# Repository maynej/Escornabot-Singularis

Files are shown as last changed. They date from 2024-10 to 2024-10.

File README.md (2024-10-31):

# Escornabot-Singularis

Es tracta d'una copia de l'estructura original i una adaptació per utilitzar una bateria recarregable. 

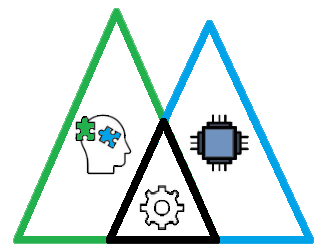
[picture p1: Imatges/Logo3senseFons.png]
Realitzada per [Jordi Mayné](https://github.com/maynej) des de Mechatronic Study 

Escornabot es un projecte obert (https://escornabot.com) 

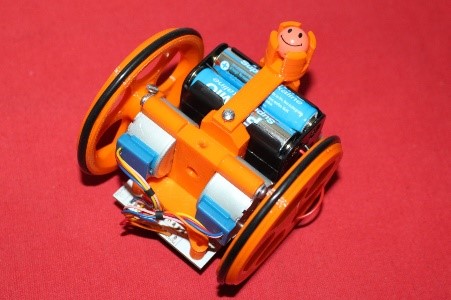
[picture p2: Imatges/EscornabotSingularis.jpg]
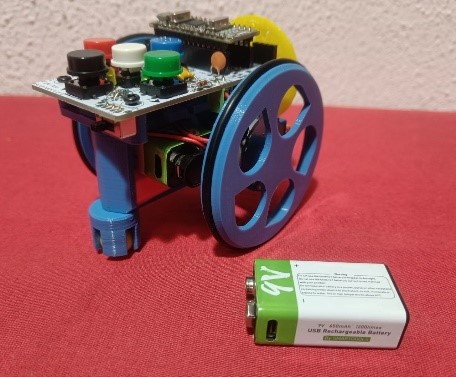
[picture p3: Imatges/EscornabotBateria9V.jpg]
 

El [Manual es pot trobar en PDF](https://github.com/maynej/Escornabot-Singularis/tree/master/DOC/). Inclós en llengua castellana, francés i anglès.

El [Funcionament del firmware es pot trobar en PDF](https://github.com/maynej/Escornabot-Singularis/tree/master/Funcionament/).

També es pot programar amb Arduinoblocks 
de mans de [Manuel Hidalgo](https://github.com/maynej/Escornabot-Singularis/tree/master/Arduinoblocks/). 

STL per imprimir [aquí](https://github.com/maynej/Escornabot-Singularis/tree/master/STL).

Material recopilat de [Xoan Sampaiño](https://github.com/xoan), [Rafa Couto](https://github.com/rafacouto), [XDeSIG](https://github.com/xdesig), [Jorge Lobo Martínez](https://github.com/lobotic) i [mgesteiro](https://github.com/mgesteiro)   
  
# Escornabot Singularis
  
Descripció         | Imatge          | STL         
------------- | ------------- | ------------- 
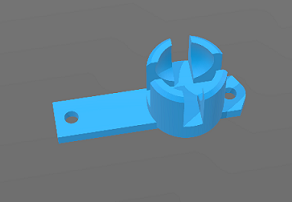
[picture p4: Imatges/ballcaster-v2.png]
Suport bola| | [Suport bola](STL/ballcaster-v2.stl)  
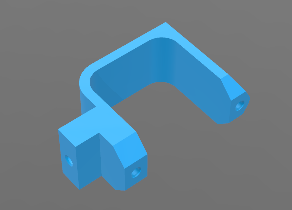
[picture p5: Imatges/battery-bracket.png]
Suport piles| | [Suport piles](STL/battery-bracket.stl)  
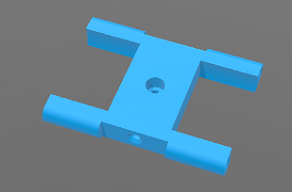
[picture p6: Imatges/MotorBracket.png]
Suport motors| | [Suport Motors](STL/MotorBracket.stl)  
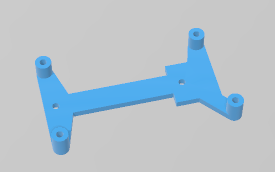
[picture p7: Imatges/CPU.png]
Suport CPU| | [Suport CPU](STL/cpu-2_10-bracket.stl)  
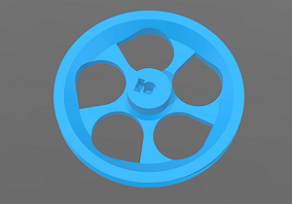
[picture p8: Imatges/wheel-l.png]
Roda esquerra| | [Roda esquerra](STL/wheel-l.stl)  
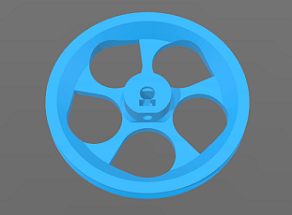
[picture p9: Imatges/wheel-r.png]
Roda dreta| | [Roda dreta](STL/wheel-r.stl)  
  
### Opcións Bateria (explicat en el Manual)
  
Descripció         | Imatge          | STL          
------------- | ------------- | ------------- 
Afegit per Bateria| | [Afegit bateria](STL/TopeBateria9V.stl)  
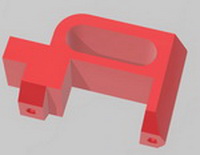
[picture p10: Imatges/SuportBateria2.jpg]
Suport Bateria| | [Suport bateria](STL/BatteryBallcaster2.stl)  

## QR



## Llicència

Creative Commons Attribution-NoComercial-ShareAlike 4.0 International (CC BY-NC-SA 4.0)

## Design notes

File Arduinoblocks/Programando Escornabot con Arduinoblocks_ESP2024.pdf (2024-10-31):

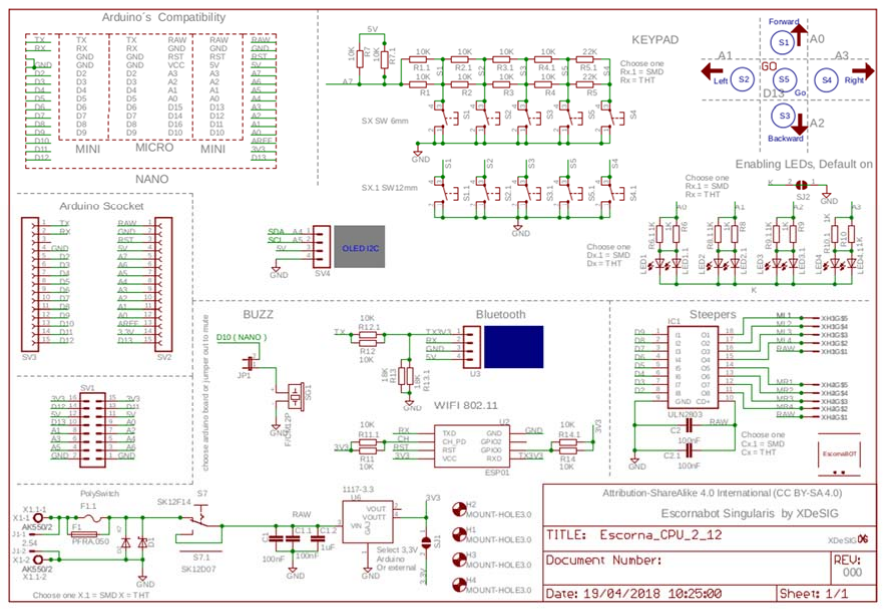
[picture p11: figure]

JORDI MAYNE 2024 | 1

Programando Escornabot con Arduinoblocks.

Manuel Hidalgo - LeoBot

Divulgador de Robóca Educava y OpenSource

hps://leobotmanuel.github.io/Programando-Escornabot/about/

El robot Escornabot es un recurso educavo apropiado para desarrollar el Pensamiento Computacional en edades tempranas por su facilidad de programar sus movimientos y su ulización transversal en casi todos los contenidos educavos de aprendizaje.

En este proyecto se va a ulizar Escornabot para aprender a programar el robot con un lenguaje de programación visual como es Arduinoblocks.

Previamente se ene que conocer el hardware del robot para desarrollar el programa de control en el microcontrolador del robot. Esta información se va a obtener de la web de Escornabot.

HARDWARE

La placa de control del robot Escornabot se denomina EscornaCPU y la úlma versión es la 2.x.

En el esquema de la versión 2.12 se ve los diferentes bloques.

CPU v.2.12

Teclado

El esquema correspondiente al bloque del teclado.

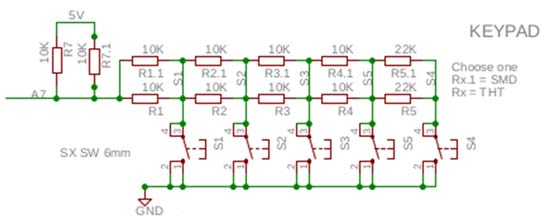
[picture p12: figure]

Teclado

Observando el esquema del teclado hay un cable equetado con A7 que va al microcontrolador (entrada analógica).

El funcionamiento del teclado es un divisor de tensión, la pulsación de cada una de las teclas va a dar un valor de tensión en función del número de resistencias en serie que estén conectadas. El valor correspondiente a cada tecla se puede obtener, por medio del monitor serie, con el siguiente programa y se anotan para ulizar posteriormente el valor de cada tecla con el movimiento a realizar.

hp://www.arduinoblocks.com/web/project/1617016

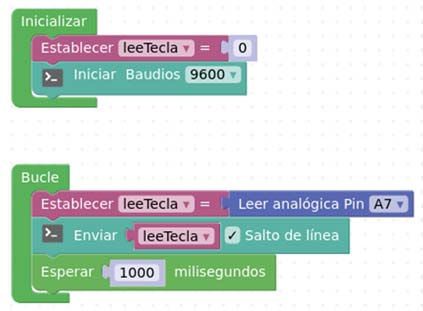
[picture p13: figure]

Programa valor teclado

LED

Cada una de las teclas ene asociado un LED que se conectan a los pines A0, A1, A2 y A3. Estos pines se ulizan como salidas digitales.

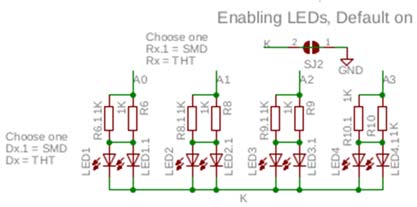
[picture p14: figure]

Esquema LED

El programa de test de los LED hp://www.arduinoblocks.com/web/project/1617023

Motores paso a paso

Los motores del robot son po paso a paso y para el control de la secuencia de movimientos de los motores paso a pasos (28byj-48) se uliza 4 pines digitales para cada uno conectados a un driver ULN2803 entre la placa Nano Arduino y los motores.

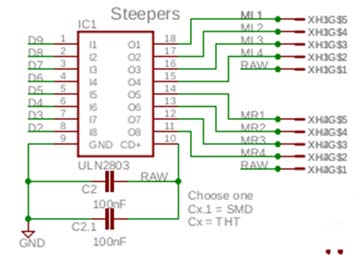
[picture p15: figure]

Pines de los motores paso a paso

Información sobre el funcionamiento de motores paso a paso en programarfacil.com.

Información y prácca de programación de los bloques de Arduinoblocks

En Arduinoblocks existe unos bloques de programación con los que se pueden hacer un programa de prueba. En el programa se indica la configuración de las conexiones en el bloque inizialización.

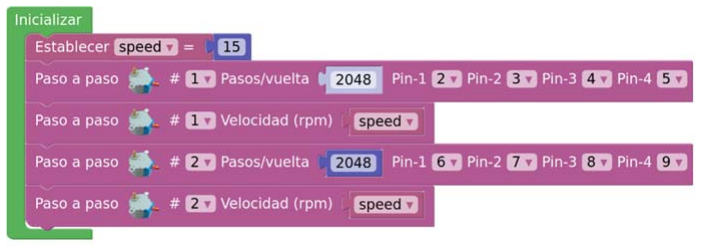
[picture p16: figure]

Configuración de las conexiones de los motores paso a paso

Desplazamiento lineal

Antes de cargar el programa de test motores paso a paso se ha de tener en cuenta cómo calcular el desplazamiento lineal de cada paso que realiza el motor.

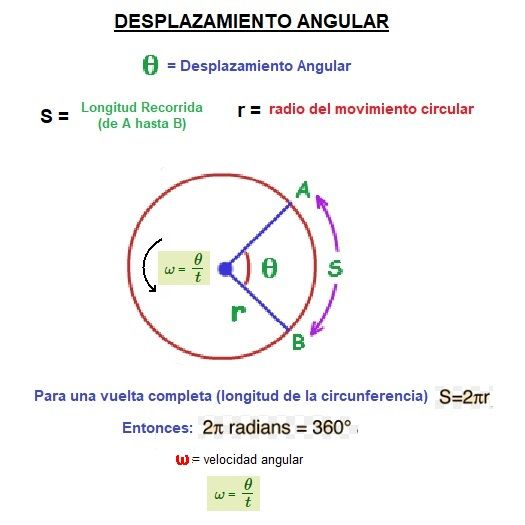
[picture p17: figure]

En el bloque de programación se ene:

2048 pasos → 1 vuelta → 360º/2048 = 0,175 º/paso

El diámetro de la rueda del robot Escornabot es de 75mm → radio = 37,5mm.

El desplazamiento lineal de cada paso

S = Θ (radianes) x r = (0,175·2·π)/360 x 37,5 = 0,114mm

Para calcular el número de paso de un desplazamiento lineal (D) en mm.

pasos = D/0,114

El programa de test para motores paso a paso

hp://www.arduinoblocks.com/web/project/editor/1617035

SOFTWARE

El programa de control de robot Escornabot va a imitar lo más parecido posible al robot original.

El algoritmo a implementar en este proyecto ene los siguientes elementos:

1. Declarar en el bloque Inicializar.
- Variables.
- Configuración de los motores paso a paso.
- Inicializar la estructura de datos para memorizar los movimientos

2. Declarar las funciones del programa.
- avanzar, retroceso, derecha, izquierda, parar, funciones de movimientos.
- grabarMovMemoria, grabar movimientos en memoria
- teclaPulsada, leer tecla pulsada.
- leerMovMemoria, leer y ejecutar los movimientos grabados.
3. Código principal Bucle.

Grabar movimientos

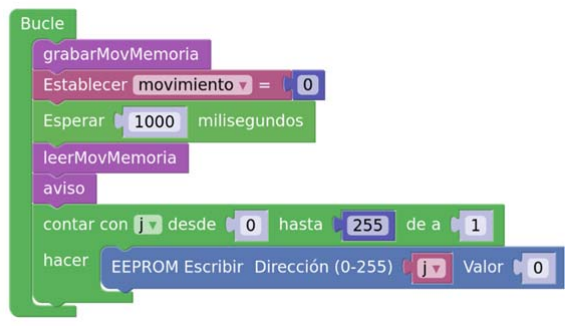
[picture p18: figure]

La función grabarMovMemoria llama a la función teclaPulsada para idenficar el número del movimiento que graba en una posición de la memoria EEPROM. Esta acción se repite hasta que se pulsa el botón central que corresponde al número 5.

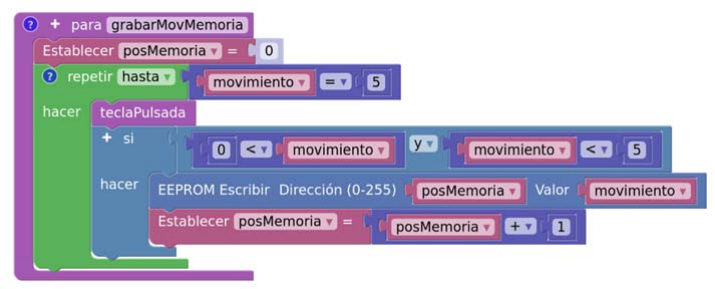
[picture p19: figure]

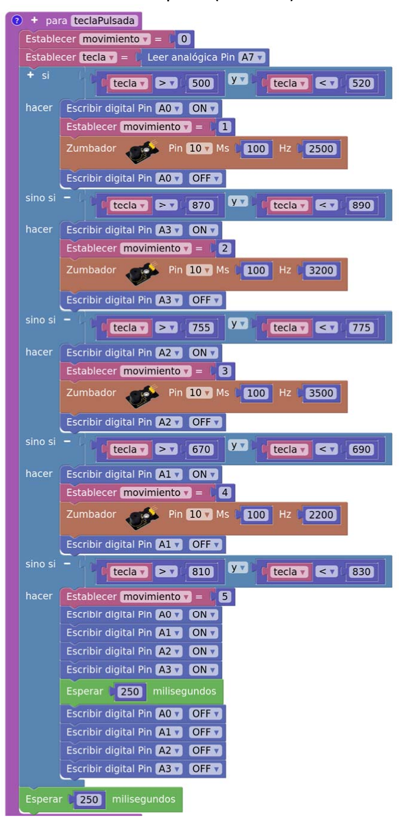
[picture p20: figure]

Leer botón pulsado (teclaPulsada)

Ejecutar los movimientos (leerMovMemoria)

Una vez grabados los movimientos que nos marca el reto con el robot Escornabot se pasa a leer los movimientos grabados en las posiciones de memoria EEPROM y cada lectura llama a la función de movimiento correspondiente.

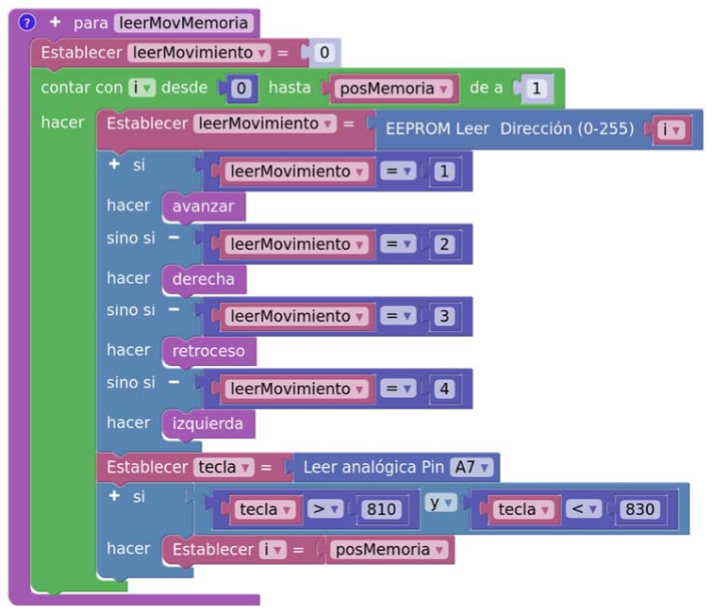
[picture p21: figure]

Esta función ene una acción complementaria que corresponde a la úlma instrucción condicional. La acción que hace es de interrumpir la secuencia de movimiento de manera voluntaria.

Funciones de movimiento

Para implementar el código de las funciones de movimiento se necesita conocer las medidas del robot Escornabot.

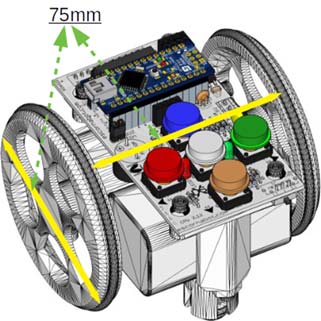
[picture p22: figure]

Se hace los cálculos de los pasos para avanzar 10cm y girar 90º con lo visto en el apartado de desplazamiento lineal de la sección Hardware. Se implementa las funciones para realizar los movimientos y al mismo empo de encinde/apaga el LED correspondiente.

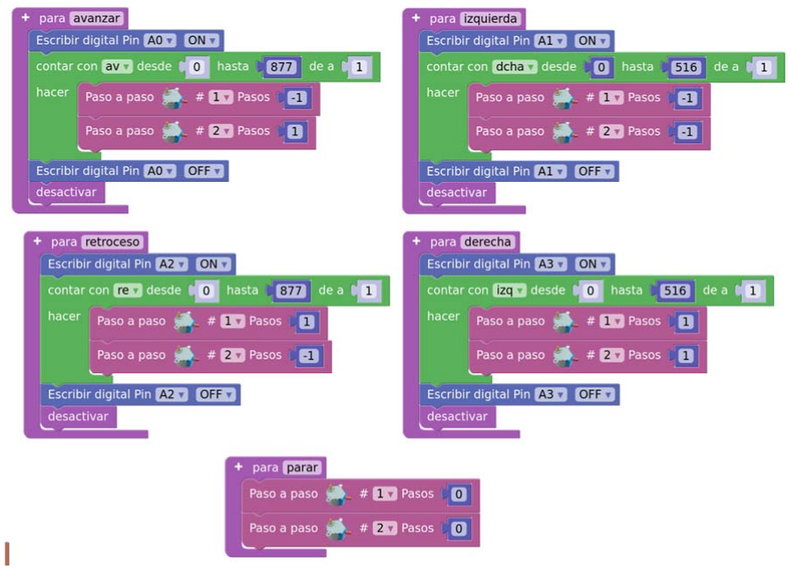
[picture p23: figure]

Funciones de Movimientos

PROGRAMAS DE CONTROL

En esta sección se encuentra diferentes programas de control del robot Escornabot programados con el lenguaje visual Arduinoblock

Programa de control con EEPROM

Programa de control completo correspondiente al taller "Programando ESCORNABOT con ARDUINOBLOCKS" del Club Robóca Granada, 20 febrero 2024.

hp://www.arduinoblocks.com/web/project/editor/1599479

Programa de control mediante lista de datos

En este link corresponde al primer programa de testeo para comprobar funcionamiento del robot Escornabot.

hp://www.arduinoblocks.com/web/project/1217118

En este programa se uliza como estructura de datos para memorizar los movimientos una lista.

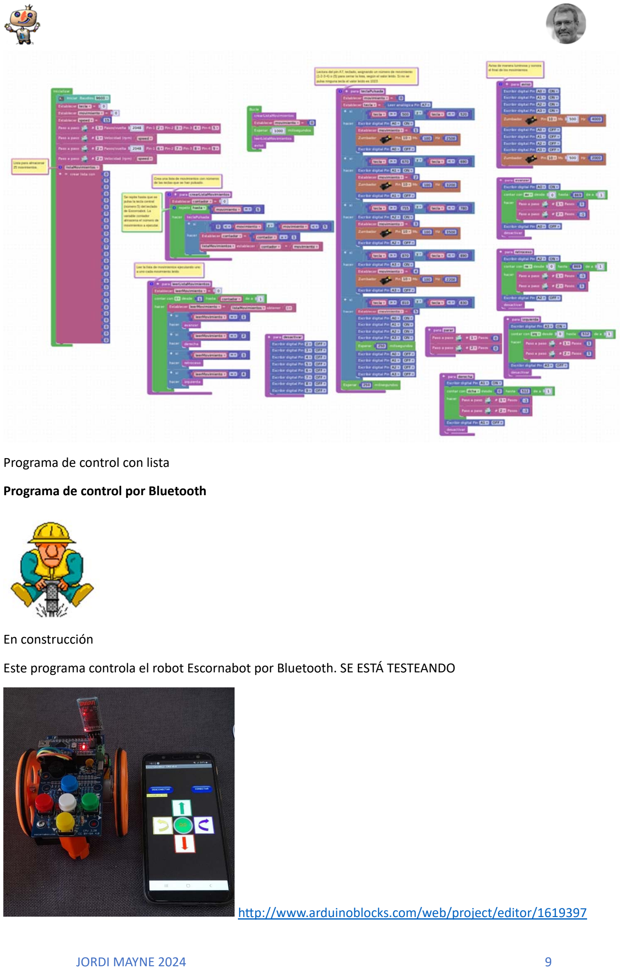
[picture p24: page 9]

Programa de control con lista

Programa de control por Bluetooth

En construcción

Este programa controla el robot Escornabot por Bluetooth. SE ESTÁ TESTEANDO

hp://www.arduinoblocks.com/web/project/editor/1619397

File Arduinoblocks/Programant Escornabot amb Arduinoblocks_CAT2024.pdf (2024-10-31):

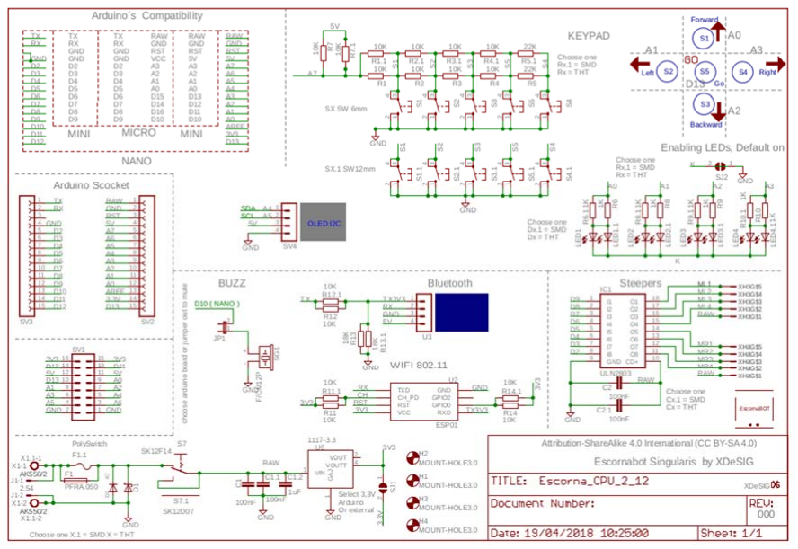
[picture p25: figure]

Traduït per Jordi Mayné 2024

Programant Escornabot amb Arduinoblocks.

Manuel Hidalgo - LeoBot

Divulgador de Robóca Educava y OpenSource

hps://leobotmanuel.github.io/Programando-Escornabot/about/

El robot Escornabot es un recurs educau apropiat per desenvolupar el Pensament Computacional en edats en edats primerenques per la facilitat de programar els moviments i la ulització transversal en gairebé tots els connguts educaus d'aprenentatge. En aquest projecte es va a ulitzar Escornabot per aprendre a programar el robot amb un llenguatge de programació visual como es Arduinoblocks.

Prèviament es te que conèixer el maquinari del robot per desenvolupar el programa de control en el microcontrolador del robot. Aquest informació es va obtenir de la web de Escornabot.

MAQUINARI

La placa de control del robot Escornabot s’anomena EscornaCPU i la darrera versió es la 2.x.

En l’esquema de la versión 2.12 es poden veure els diferents blocs.

CPU v.2.12

Teclat

L’esquema corresponent al bloc del teclat.


Teclat

Observant l’esquema del teclat hi ha un cable equetat amb A7 que va al microcontrolador (entrada analògica).

El funcionament del teclat es un divisor de tensió, la pulsació de cada una de les tecles dona un valor de tensió en funció del número de resistències en sèrie que estan connectades. El valor corresponent a cada tecla es pot obtenir, mitjançant el monitor sèrie, amb el següent programa i s’anoten per ulitzar posteriorment el valor de cada tecla amb el moviment a realitzar.

hp://www.arduinoblocks.com/web/project/1617016


Programa valor teclat

LED

Cada una de les tecles te associat un LED que es connecten als pins A0, A1, A2 i A3. Aquests pins s’ulitzen com sordes digitals.


Esquema LED

Programa de test dels LED hp://www.arduinoblocks.com/web/project/1617023

Motors pas a pas

Els motors del robot són del pus pas a pas i per el control de la seqüència de moviments dels motors pas a pas (28byj-48) s’ulitzen 4 pins digitals per cada un connectats a través d’un driver ULN2803 entre la placa Arduino Nano i els motors.


Pines de los motores paso a paso

Informació sobre el funcionament de motors pas a pas a programarfacil.com.

Información y prácca de programación de los bloques de Arduinoblocks

En Arduinoblocks existeixen uns blocs de programació amb els que es pot fer un programa de proba. En el programa s’indica la configuració de les connexions en el bloc d’inicialització.

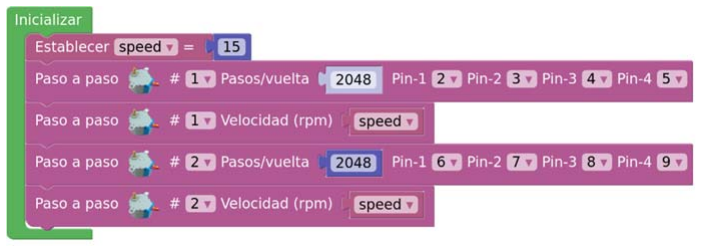
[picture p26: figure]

Configuració de les connexions dels motors pas a pas

Desplaçament lineal

Abans de carregar el programa de test de motors pas a pas s’ha de tenir en compte com calcular el desplazamiento lineal de cada pas que realitza el motor.


En el bloc de programació es te 2048 passos → 1 volta → 360º/2048 = 0,175 º/pas

El diàmetre de la roda del robot Escornabot es de 75mm → radi = 37,5mm.

El desplaçament lineal de cada pas S = Θ (radians) x r = (0,175·2·π)/360 x 37,5 = 0,114mm

Per calcular el número de passos d’un desplaçament lineal (D) en mm. passos = D/0,114

El programa de test per motors pas a pas hp://www.arduinoblocks.com/web/project/editor/1617035

PROGRAMARI

El programa de control de robot Escornabot vol imitar el més semblant possible al robot original.

L’algoritme a implementar en aquest projecte te els següents elements:

1. Declarar en el bloc Inicialitzar.
- Variables.
- Configuració dels motors pas a pas.
- Inicialitzar l’estructura de dades per memoritzar els moviments
2. Declarar les funcions del programa.
- avançar, retrocedir, dreta, esquerra, parar, funcions de moviments.
- grabarMovMemoria, gravar moviments en memòria
- teclaPulsada, llegir la tecla polsada.

- leerMovMemoria, llegir i executar els moviments gravats.
3. Codi principal Bucle.

Gravar moviments

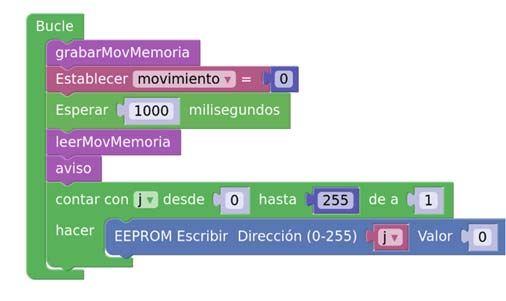
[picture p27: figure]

La funció grabarMovMemoria crida a la funció teclaPulsada per idenficar el número del moviment que grava en una posició de la memòria EEPROM. Aquesta acció es repeteix fins que es polsa el botó central que correspon al número 5.

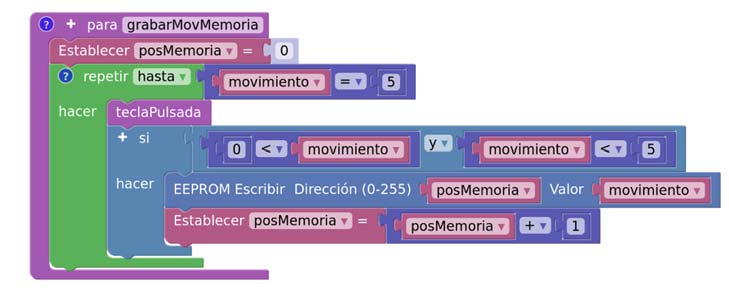
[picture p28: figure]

Llegir botó polsat (teclaPulsada)

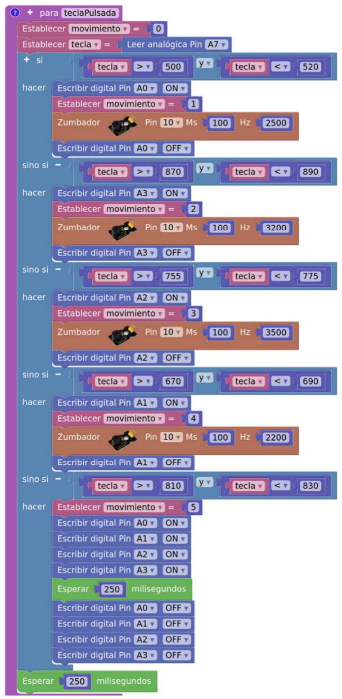
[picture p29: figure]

Executar els moviments (leerMovMemoria)

Una vegada gravats els moviments que ens marca el repte amb el robot Escornabot es passa a llegir els moviments gravats en les posicions de memòria EEPROM i cada lectura crida a la funció de moviment corresponent.

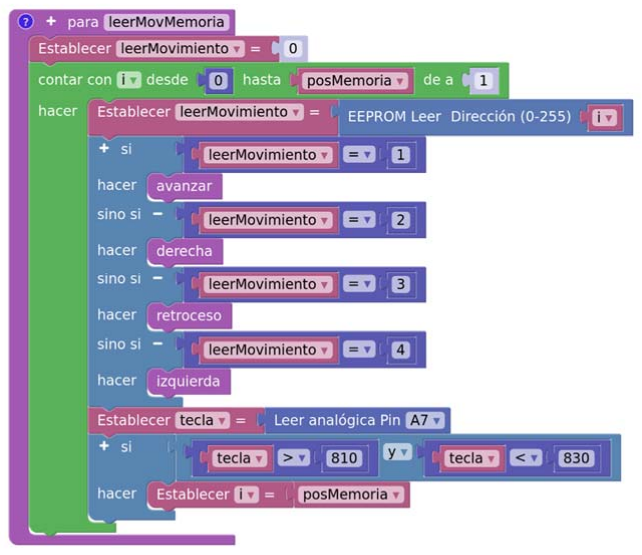
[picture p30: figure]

Aquesta funció te una acció complementaria que correspon a la darrera instrucció condicional. L’acció que fa es interrompre la seqüencia de moviment de manera voluntària.

Funcions de moviment

Per implementar el codi de les funcions de moviment es necessita conèixer les mesures del robot Escornabot.

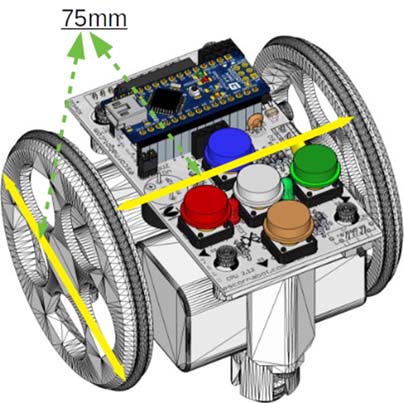
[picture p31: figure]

Es fan els càlculs dels passos per avançar 10cm i girar 90º amb el que s’ha vist en el apartat de desplazamiento lineal de la secció Maquinari. S’implementa les funcions per realitzar els moviments i al mateix temps de encén/apaga el LED corresponent.

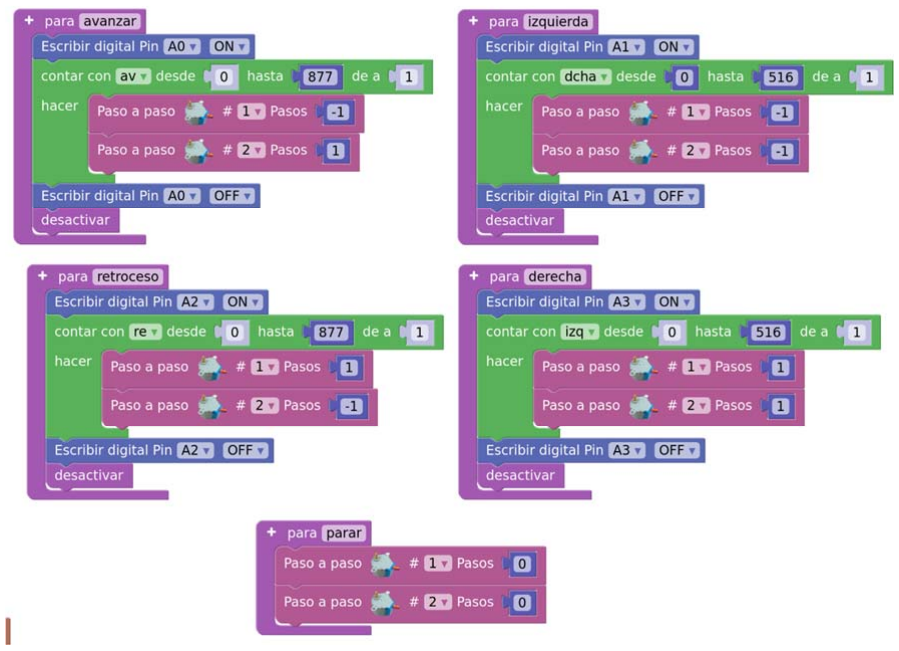
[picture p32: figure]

Funcions de Moviments

PROGRAMAS DE CONTROL

En aquesta secció es troben diferents programes de control del robot Escornabot programats amb el llenguatge visual Arduinoblock

Programa de control con EEPROM

Programa | de | control | complet | corresponent | al | taller "Programando | ESCORNABOT | con
ARDUINOBLOCKS" del Club Robóca Granada, 20 febrero 2024.

hp://www.arduinoblocks.com/web/project/editor/1599479

Programa de control mitjançant la llista de dades

En aquest enllaç correspon al primer programa de prova per comprovar funcionament del robot Escornabot.

hp://www.arduinoblocks.com/web/project/1217118

En aquest programa s’ulitza com estructura de dades per memoritzar els moviments en una llista.

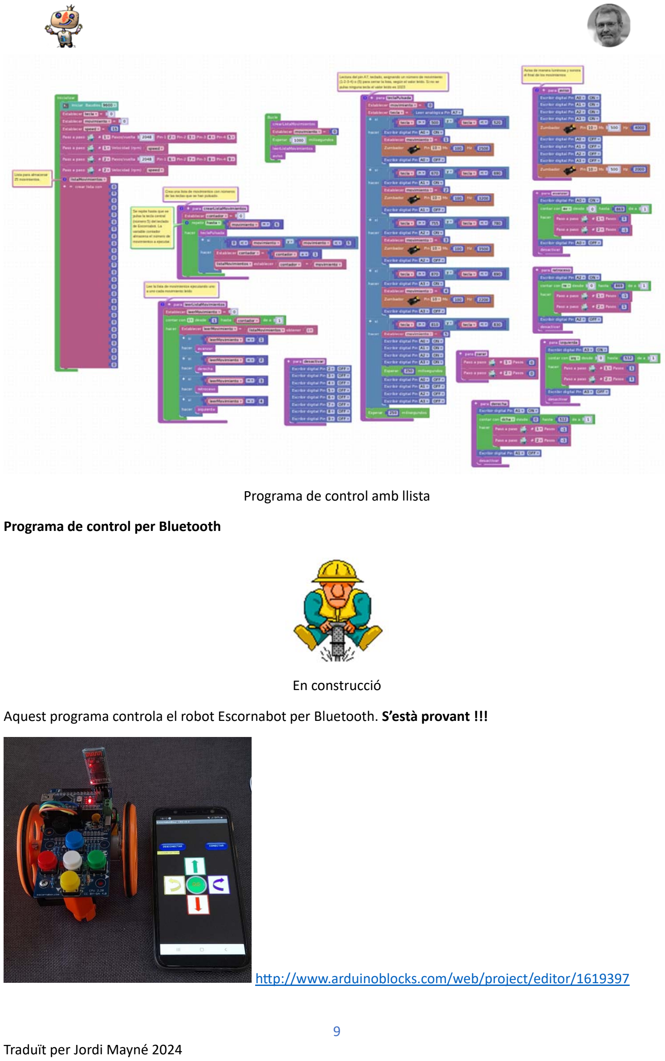
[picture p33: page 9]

Programa de control amb llista

Programa de control per Bluetooth

En construcció

Aquest programa controla el robot Escornabot per Bluetooth. S’està provant !!!

hp://www.arduinoblocks.com/web/project/editor/1619397

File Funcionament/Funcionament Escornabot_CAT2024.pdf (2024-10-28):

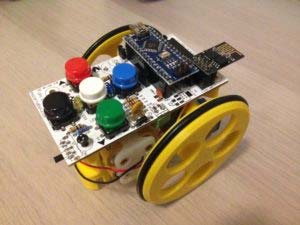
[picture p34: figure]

1 | Jordi Mayné | v0.2021

## Entendre el Programa de Funcionament d’Escornabot

### Introducció

Escornabot pot executar seqüencies de moviments que son programats pel usuari mitjançant la pulsació de les tecles del robot. També es pot ampliar el seu control amb un telèfon mòbil o una “tablet” a través de Bluetooth o Wifi.

L’Escornabot disposa d’un interruptor general de posta en marxa i 4 botons
que permet programar els moviments que volem que faci, cada pulsació programada farà avançar 10 cm, permet moure endavant (tecla blava), moure enrere (tecla negre), girar a l’esquerra (tecla vermella), girar a la dreta (tecla verda) i la tecla del mig de color blanc farà que executi la seqüencia programada. També la tecla blanca pot parar la seqüencia quan l’Escornabot està en marxa.

### Components de l’Escornabot versió Singularis

- 2 motors per moure cada roda
- 1 processador per la seqüencia de les ordres cap els motores i LEDs de senyalització.
- 1 memòria per guardar les ordres.
- 5 tecles per polsar les ordres.
- 5 llums d’indicació.
- Brunzidor per sentir que està fent.
- 4 piles per donar energia a l’Escornabot.
- Interruptor per posar para posar en marxa.

### Esquema de l’Escornabot Singularis


### Processador Arduino

La unitat de control de procés Arduino es el cervell del robot, es on es guarden les instruccions rebudes des del teclat i on es controlen els motors, LEDs i brunzidor. També incorpora un connector USB per poder actualitzar el firmware del robot.

Aquest placa de circuit imprès d’Arduino (anomenada Arduino Nano) conté un microcontrolador de 8 bit del fabricant Microchip de la família AVR (abans Atmel) ATMEGA328P, incorpora en el seu interior la unitat central de procés (CPU), una memòria Flash de 32KBytes (on hi ha el programa y es pot reprogramar), una memòria RAM 2 KBytes (per emmagatzemar valors temporalment, ja que quan es treu l’alimentació es perden aquestes dades i una memòria Eeprom 1 KBytes (on es guarden dades durant l’execució d’un programa i romandran encara que es tregui l’alimentació).


Entrades analògiques van al convertidor analògic digital (ADC de 10 bit) i les sortides analògiques poden ser PWM (pera el control de motores).

Entrades/sortides digitals i altres permeten una comunicació sèrie (I2C, SPI y UART). Un pin de Reset que va al polsador de la placa.

Una part imprescindible es un rellotge de quars de 16 MHz amb un oscil·lador fins 20MHz que equival a poder executar 20 milions de instruccions per segon.

Una anotació més sobre la memòria Flash, es on es programa un firmware anomenat Bootloader (que ocupa 0,5 KBytes), permet carregar el programa que podem fer via sèrie a través del USB.

Aquesta placa s’alimenta amb 5V

### Motor pas a pas

L’Escornabot incorpora dos motors pas a pas, vol dir que es mouen per impulsos, dintre del motor incorporen una reductora, cada 64 polsos dona una volta, que permet una gran precisió. Segons la freqüència dels polsos proporcionen la velocitat.

Si giren en el mateix sentit el robot avança o retrocedeix, si un gira en un sentit i l’altre en
sentit contrari, el robot girarà 90 graus cap a la dreta o 90 graus cap a l’esquerra.

Hi ha una nova revisió del firmware, la 1.6, que pot girar a 60 o a 90 graus, aquest es per usuaris més avançats al permetre anar en diagonal.

Aquest tipus de motor pas a pas es de 4 fases Unipolar i s’utilitza la commutació de Mig Pas.


En aquesta configuració de control anomenada de Mig Pas, les dues bobines que tenen un punt mig formant quatre bobines, es poden veure com es van alternant los polsos en la taula anterior per realitzar els moviments pas a pas. Es necessiten 4 passos, un gir en vuit cicles i un gir complert de l’eix exterior 64 voltes del rotor, per el que es requereixen 2048 passos per una volta.

### Nº de passos per una volta = 4 x 8 x 64 = 2048

Amb el següent codi aconseguirem una volta completa del motor:

const static uint8_t step_pattern[] = {
B00001, B00011, B00010, B00110, B00100, B01100, B01000, B01001 } ;

Es pot constatar que el patró del codi correspon a la taula de seqüencia de commutació de Mig Pas, cada 1 en la taula apareix un punt en vermell.


El corrent de cada bobina es relativament alta i es necessari posar un “driver” per que el microcontrolador no entregui aquest corrent si no que la entrega cada transistor intern.

### Control del teclat

El teclat està minimitzat per només fer servir un sols pin, utilitzant una entrada analògica de la següent manera.


El convertidor analògic/digital del microcontrolador “llegeix” el valor de voltatge del pin d’entrada A7 i “entén” quin botó s’ha polsat.

### Cóm es programa?

Escornabot fa servir un mòdul d’Arduino, molt popular en el mon DIY, on es grava el firmware de funcionament, que està totalment disponible i documentat en https://github.com/escornabot

Es fa servir l’entorn de desenvolupament d’Arduino i es pot fer com un taller de informàtica el desenvolupament complet o parcial del seu funcionament, evidentment adequant-lo a l’edat corresponent.


### Entendre el programa de funcionament

El programa d’aquest Escornabot ha estat realitzat per @caligari, seguidament es descriurà la part principal de funcionament.

Al obrir el firmware 1.4.3 o 1.6.2 Escornabot.ino amb l’entorn d’Arduino, apareixen una sèrie de pestanyes on es mostra cada part del control.


L’estructura del llenguatge de programació es similar a C++, el programa es pot executar en dues parts:
- void setup() es la configuració i es troba sempre al inici del programa, es configuren els pinMode, s’inicialitza la comunicació sèrie, etc i s’executarà una sola vegada després de cada encesa o després d’un Reset amb el polsador de la placa.
- void loop() es l’execució del codi, como lectura d’entrades i activació de sortides.

L’arxiu Configuration.h es on s’allotja la part més important per entendre el funcionament, la Configuració.

Quan hi ha una línia que comença amb dos // o més vol dir que a continuació només són comentaris que ha posat el programador per entendre el seu programa. El programa original està en color verd i els comentaris addicionals per detallar en color vermell.

Si no es tenen coneixements de programació en C++ o C per Arduino, es pot veure una documentació molt ben detallada http://manueldelgadocrespo.blogspot.com/p/se-utiliza-para-la-comunicacion-entre_3.html

//////////////////////////////////////////////////////////////////////
///// general configuration //////////////////////////////////////////////////////////////////////

// engine to use Defineix el motor a utilitzar, en aquest cas motor pas a pas
#define ENGINE_TYPE_STEPPERS

#define en C es un component útil que permet al programador donar un nom a un valor constant abans de compilar el programa. Les constants definides en Arduino no ocupen cap espai de memòria de programa en el xip. El compilador reemplaça les referències a aquestes constants amb el valor definit en temps de compilació. En Arduino define te la mateixa sintaxis que define en C:

No hi ha un punto i coma desprès de la instrucció #define. Si s’inclou un, el compilador generarà errors. Tampoc pot haver un signe (=) a un número valor (5) o (true), per exemple.

// button set to use (analog input, digital input) Configura el tipus d’entrada que prové de polsadors Analògics o Digitals
#define BUTTONS_ANALOG Defineix el tipus d’entrada que prové de polsadors Analògics

//#define BUTTONS_DIGITAL Defineix el tipus de entrada que prové de polsadors Digitals (no està activat)

// milliseconds after a button is considered as pressed Defineix quants mili-segons, com a mínim, te que estar polsat un botó, para evitar polsos paràsits inesperats en aquesta línia de polsadors.
#define BUTTON_MIN_PRESSED 30 // En aquest cas 30 ms

// milliseconds after a button is considered as long pressed Defineix quants mili-segons, com a mínim, te que estar polsat un botó, per considerar que es tracte d’una pulsació “llarga”, per configurar girs de 60 graus.
#define BUTTON_LONG_PRESSED 1000 // En aquest cas 1000 ms que determina pulsació llarga

// put to false to add movements to the program after its execution
#define PROGRAM_RESET_ALWAYS true // Fa un Reset dels moviments al final d’executar-se un cicle programat.

// store configuration and program within internal EEPROM
#define USE_PERSISTENT_MEMORY false // Serviria per emmagatzemar en l’Eeprom els moviments, però, no s’utilitza aquesta funcionalitat

// memory capacity for program movements Defineix la quantitat de moviments que es poden emmagatzemar en la memòria RAM
#define MOVE_LIMIT 100 // En aquest cas es podran emmagatzemar fins a 100 moviments, es pot ampliar el número de moviments programat, ocupant més memòria RAM, que es comparteix amb la que usa el propi programa, però, típicament es suficient. El microcontrolador ATMega328P de la placa Arduino disposa de 2K bytes de RAM i no en sobra molta, però, es podria, si fos necessari, configurar para emmagatzemar més moviments, però, no s’ha provat el límit).

// milliseconds for the "pause" movement Defineix quants mili-segons tindrà que estar polsat el botó per programar una pausa
#define PAUSE_MOVE_MILLIS 1000 // En aquest cas 1000 ms, que determina una Pausa

// milliseconds delay before starting to move Defineix quants mili-segons esperarà el robot per començar a moure’s
#define DELAY_BEFORE_GO 500 // En aquest cas començarà a moure’s després de 500 ms

// milliseconds to pause after every movement Defineix quants mili-segons tindrà que estar polsat el botó per programar una pausa
#define AFTER_MOVEMENT_PAUSE 0 // En aquest cas començarà a moure’s després de 0 ms desprès de una Pausa

// point of view set when Vacalourabot is started Escornabot (abans Vacalourabot)
#define POV_INITIAL POV_ESCORNABOT // Punt de vista (Point Of View) de l’execució dels moviments, es a dir des de l’usuari o des del robot, però, no està implementat

// bluetooth serial Defineix el port sèrie que prové del mòdul Bluetooth
#define USE_BLUETOOTH true // Defineix l’ús del mòdul Bluetooth

#define BLUETOOTH_BAUDS 9600 // Defineix la velocitat de transmissió del mòdul Bluetooth

// buzzer Defineix el Brunzidor
#define USE_BUZZER true // Defineix l’ús del mòdul Bluetooth

#define BUZZER_PIN 10 // Defineix el pin usat per el Brunzidor (En aquest cas D10)

#define PROGRAM_FINISHED_RTTL RTTL_FIDO // Buzzer,h // Defineix la musiqueta al final de l’execució #define TONE_FREQ_UP 2637 // Defineix la freqüència de 2637 (que correspon a un Mi octava 7 musical) per senyalitzar que va endavant

#define TONE_FREQ_RIGHT 4434 // Defineix la freqüència de 4434 (que correspon a un Do# octava 8 musical) per senyalitzar que gira a la dreta

#define TONE_FREQ_DOWN 3520 // Defineix la freqüència de 3520 (que correspon a un La octava 7 musical) per senyalitzar que va enrere

#define TONE_FREQ_LEFT 2217 // Defineix la freqüència de 2217 (que correspon a un Do# octava 7) per senyalitzar que gira a l’esquerra

Control del Brunzidor

Una sortida PWM del microcontrolador genera freqüències que es poden reproduir en un brunzidor

En aquesta web es poden trobar cada nota musical amb el seu corresponent freqüència i octava corresponent: https://juegosrobotica.es/musica-con-arduino/#

Control del LED

// simple led Defineix el LED
#Define USE_SIMPLE_LED false // Defineix l’ús del LED #Define SIMPLE_LED_PIN 13 // Defineix el pin 13 pel LED

// keypad leds Defineix els LED dels polsadors
#Define USE_KEYPAD_LEDS true

#Define KEYPAD_LED_PIN_UP A0 // Defineix el pin A0 pel LED per senyalitzar que va endavant #Define KEYPAD_LED_PIN_RIGHT A3 // Defineix el pin A3 pel LED per senyalitzar que gira a la dreta #Define KEYPAD_LED_PIN_DOWN A2 // Defineix el pin A2 pel LED per senyalitzar que va enrere #Define KEYPAD_LED_PIN_LEFT A1 // Defineix el pin A1 pel LED per senyalitzar que gira a l’esquerra #Define KEYPAD_LED_PIN_GO 13 // Defineix el pin 13 pel LED per senyalitzar que es posa en marxa

////////////////////////////////////////////////////////////////////// ///// Steppers engine setup // Configura els motors pas a pas //////////////////////////////////////////////////////////////////////

#ifdef ENGINE_TYPE_STEPPERS

#ifdef permet compilar una secció d’un programa sols si la macro que s’especifica com paràmetre ha estat definida, sense importar el valor que sigui.

// stepper pin setup (digital outputs) Configuració dels pins de control dels motors pas a pas
#Define STEPPERS_MOTOR_RIGHT_IN1 5

#Define STEPPERS_MOTOR_RIGHT_IN2 4

#Define STEPPERS_MOTOR_RIGHT_IN3 3

#Define STEPPERS_MOTOR_RIGHT_IN4 2 #Define STEPPERS_MOTOR_LEFT_IN1 9 #Define STEPPERS_MOTOR_LEFT_IN2 8

#Define STEPPERS_MOTOR_LEFT_IN3 7

#Define STEPPERS_MOTOR_LEFT_IN4 6

// stepper pin setup (digital outputs) Configuració dels pins de control dels motors pas a pas amb gir invers #Define STEPPERS_MOTOR_RIGHT_IN1 2
#Define STEPPERS_MOTOR_RIGHT_IN2 3

#Define STEPPERS_MOTOR_RIGHT_IN3 4

#Define STEPPERS_MOTOR_RIGHT_IN4 5 #Define STEPPERS_MOTOR_LEFT_IN1 6 #Define STEPPERS_MOTOR_LEFT_IN2 7

#Define STEPPERS_MOTOR_LEFT_IN3 8

#Define STEPPERS_MOTOR_LEFT_IN4 9

// step calibration Configuració de la calibratge dels passos
#Define STEPPERS_STEPS_PER_SECOND 1000 // Defineix el número de passos per segon, es pot modificar fins a 2300 passos, però, depèn del motor i també de l’alimentació de la bateria

#Define STEPPERS_LINE_STEPS 1738 // Defineix el número de passos per cada pas (10 cm), es pot crear un tapet de joc amb dimensions diferents, 1cm serà de 174. A partir d’aquí podem canviar el valor per que avanci el que volem.

#Define STEPPERS_TURN_STEPS 1024 // Defineix el número de passos per cada gir (90 graus), per girar a 45 graus es pot modificar a 512 passos, En cas de decimals arrodonir el valor.

Un joc; practicar les hores del rellotge variant els angles de gir.

#endif

Aquestes directives permeten incloure o descartar part del codi d’un programa si es compleix una determinada condició.
#ifdef permet compilar una secció d’un programa sols si la macro que s’especifica com paràmetre ha estat definida, sense importar quin sigui el seu valor.

Por exemple, si tenim una aplicació i t’agrediria que quan estiguis desenvolupament, sempre inicií amb un usuari determinat.

En aquest cas, aquestes directives et poden ajudar:
#Define PRUEBA

#ifdef PRUEBA

// CODIGO PARA CARGAR USUARIO POR DEFECTO

#endif

El codi de l’interior de la directiva sols serà compilat si PRUEBA està definida. Així quan vagis a publicar la teva aplicació, sols tindries que eliminar la definició de PRUEBA i el programa seguirà el seu flux normal.

Control dels Polsadors
Com s’ha mostrat al principi els polsadors estan enllaçats amb resistències a un sols pin, en l’arxiu Configuration.h

Per el que aquesta part de configuració Digital no està activada

////////////////////////////////////////////////////////////////////// ///// Button set digital
//////////////////////////////////////////////////////////////////////

#ifdef BUTTONS_DIGITAL

// keypad pin setup (digital or analog inputs) (use 255 if key doesn't exist) #Define BS_DIGITAL_UP A0
#Define BS_DIGITAL_RIGHT A1

#Define BS_DIGITAL_DOWN A2

#Define BS_DIGITAL_LEFT A3 #Define BS_DIGITAL_GO A4

#Define BS_DIGITAL_RESET 255

#endif // BUTTONS_DIGITAL

Aquesta part si que funciona

////////////////////////////////////////////////////////////////////// ///// Button set analog
//////////////////////////////////////////////////////////////////////

#ifdef BUTTONS_ANALOG

#Define BS_ANALOG_WIRES 2 // WIRE 2 ?

//#Define BS_ANALOG_WIRES 3 // no s’usa

// keypad pin setup (analog input)
#Define BS_ANALOG_PIN A7 // Configura el pin A7 com entrada dels Polsadors

// input values for each key pressed (0 if key doesn't exist)
#Define BS_ANALOG_VALUE_UP 512 // Valors para Polsador Endavant #Define BS_ANALOG_VALUE_RIGHT 860 // Valors para Polsador Dreta #Define BS_ANALOG_VALUE_DOWN 769 // Valors para Polsador Enrere #Define BS_ANALOG_VALUE_LEFT 683 // Valors para Polsador Esquerra

#Define BS_ANALOG_VALUE_GO 810 // Valors per Polsador GO #Define BS_ANALOG_VALUE_RESET 0 // Valors per RESET ?

#endif // BUTTONS_ANALOG

////////////////////////////////////////////////////////////////////// ///// Button set Bluetooth //Configuració del Bluetooth //////////////////////////////////////////////////////////////////////

#ifdef USE_BLUETOOTH

// Arduino serial port (default is Serial, use Serial1 with Arduino Micro)
//#Defineix BLUETOOTH_SERIAL Serial si trèiem les barres // ja deixa preparat per rebre dades a través del mòdul Bluetooth
//#Define BLUETOOTH_SERIAL Serial1
//#Define BLUETOOTH_SERIAL Serial2
//#Define BLUETOOTH_SERIAL Serial3

#endif // USE_BLUETOOTH

Modo de joc a 90 o 60 graus
El firmware està preparat per treballar a 90 graus i a 60 graus amb pulsació llarga. La selecció del tipus de joc ve definida en l’archivo Enums.h

// game modes
enum
{
GAME_MODE_GRID_90 = 0, // squared grid (classical mode) GAME_MODE_GRID_60 = 1, // triangled grid
};
typedef uint8_t GAME_MODE;

Programació dels moviments de “Salutació”
Els moviments de “salutació” inicial al alimentar l’Escornabot, estan programats en la memòria Eeprom del microcontrolador, on queden emmagatzemades encara que es tregui de nou l’alimentació i en el firmware està en l’arxiu MoveList.h

const static MOVE PROGRAM_ESCORNA_GREETING[] = {
MOVE_FORWARD, // Mou cap endavant
MOVE_LEFT, | // Mou cap a l’esquerra
MOVE_RIGHT, | // Mou cap a la dreta
MOVE_RIGHT, | // Mou cap a la dreta
MOVE_LEFT, | // Mou cap a l’esquerra
MOVE_BACKWARD, // Mou cap enrere MOVE_NONE
};

Si es volen programar altres moviments, sols hi ha que modificar, treure o afegir las línies que es mostren en l’arxiu MoveList.h . El número de moviments como es pot veure són 6, però, la memòria Eeprom permet una quantitat elevada de moviments, te 1 KBytes

### Escornabot segueix creixent

A més, Escornabot està preparat per afegir un mòdul de Bluetooth tipus HM-10 amb la App disponible per Android i IOs.


També està preparat per un mòdul Wifi, encara que no es recomanable típicament per l’alt consumo amb respecte al mòdul Bluetooh, però, es possible.

El control remot no es recomanable per els usuaris de menor edat, ja que es millor treballar sobra d’una taula o en el terra. En canvi, l’ús de control remot permet realitzar un altre tipus de pràctiques com el disseny d’un control des d’un telèfon amb AppInventor.

EngineSteppers.cpp

Es on fa girar en un sentit o un altre els motors

void EngineSteppers::init()

{

pinMode(_config->motor_left_in1, OUTPUT);

pinMode(_config->motor_left_in2, OUTPUT);

pinMode(_config->motor_left_in3, OUTPUT);

pinMode(_config->motor_left_in4, OUTPUT);

pinMode(_config->motor_right_in1, OUTPUT);

pinMode(_config->motor_right_in2, OUTPUT);

pinMode(_config->motor_right_in3, OUTPUT);

pinMode(_config->motor_right_in4, OUTPUT);

// set coils in row // just al alimentar fa aquest petit moviment per estabilitzar la posició de las bobines dels motors

_movement_steps_r = 8;

_movement_steps_l = 8;

EVENTS->add(this);

}

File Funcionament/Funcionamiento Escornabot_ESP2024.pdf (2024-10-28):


1 | Jordi Mayné | v0.2021

## Entender el Programa de Funcionamiento de Escornabot

### Introducción

Escornabot puede ejecutar secuencias de movimientos que son programados por el usuario mediante la pulsación de las teclas del robot. También se puede ampliar su control manejándose desde un teléfono móvil
o una “tablet” a través de Bluetooth o Wifi.

El Escornabot dispone de un interruptor general de puesta en marcha y 4 botones que permite programar los movimientos que queremos que haga, cada pulsación programada hará avanzar 10 cm, permite mover hacia adelante (tecla azul), mover hacia atrás (tecla negra), girar a la izquierda (tecla roja), girar a la derecha (tecla verde) y la tecla del medio de color blanco hará que ejecute la secuencia programada. También la tecla blanca puede parar la secuencia cuando el Escornabot está en marcha.

### Componentes de Escornabot versión Singularis

- 2 motores para mover a cada rueda
- 1 procesador para la secuencia las ordenes hacia los motores y LEDs de señalización.
- 1 memoria para guardar las órdenes.
- 5 teclas para pulsar las órdenes.
- 5 luces de indicación.
- Zumbador para oir que está haciendo.
- 4 pilas para dar energía al Escornabot.
- Interruptor para poner en marcha.

### Esquema del Escornabot Singularis


### Procesador Arduino

La unidad de control de proceso Arduino es el cerebro del robot, es donde se guardan las instrucciones recibidas desde el teclado y donde se controlan los motores, LEDs y zumbador. También incorpora un conector USB para poder actualizar el firmware del robot.

Esta placa de circuito impreso de Arduino (llamada Arduino Nano) contiene un microcontrolador de 8 bit del fabricante Microchip de la familia AVR (antes Atmel) ATMEGA328P, incorpora en su interior la unidad central de proceso (CPU), una memoria Flash de 32KBytes (donde se alberga el programa y se puede reprogramar), una memoria RAM 2 KBytes (para almacenar valores temporalmente, ya que cuando se quita alimentación se pierden estos datos y una memoria Eeprom 1 KBytes (donde se guardan datos durante la ejecución de un programa y permanecerán aunque se quite alimentación).


Entradas analógicas van al convertidor analógico digital (ADC de 10 bit) y las salidas analógicas pueden ser PWM (para el control de motores).

Entradas/salidas digitales y otras permiten una comunicación serie (I2C, SPI y UART). Un pin de Reset que va al pulsador de la placa.

Una parte imprescindible es un reloj de cuarzo de 16 MHz con un oscilador de hasta 20MHz que equivale a poder ejecutar 20 millones de instrucciones por segundo.

Un apunte más sobre la memoria Flash, es donde se programa un software llamado Bootloader (que ocupa 0,5 KBytes), permite cargar el programa que realicemos vía serie a través del USB.

Esta placa se alimenta con 5V

### Motor paso a paso

El Escornabot incorpora dos motores paso a paso, quiere decir que se mueven por impulsos, dentro del motor incorporan una reductora, cada 64 pulsos dan una vuelta, que permite una gran precisión. Según la frecuencia de los pulsos proporcionan la velocidad.

Si giran en el mismo sentido el robot avanza o retrocede, si uno gira en un sentido y el otro
en sentido contrario, el robot girará 90 grados hacia la derecha o 90 grados hacia la izquierda.

Hay una nueva revisión de firmware, la 1.6, que puede girar a 60 y a 90 grados, esto es para usuarios más grandes, y permite ir en diagonal.

Este tipo de motor paso a paso es de 4 fases Unipolar y se utiliza la conmutación de Medio Paso.


En esta configuración de control llamada de Medio Paso, las dos bobinas que tienen un punto medio formando cuatro bobinas, se puede ver cómo se van alternando los pulsos en la tabla anterior para realizar los movimientos paso a paso. Se necesitan 4 pasos, un giro en ocho ciclos y un giro completo del eje exterior 64 vueltas del roto, por lo que se requieren 2048 pasos para una vuelta.

### Nº de pasos para una vuelta = 4 x 8 x 64 = 2048

Con el siguiente código conseguimos una vuelta completa del motor:

const static uint8_t step_pattern[] = {
B00001, B00011, B00010, B00110, B00100, B01100, B01000, B01001 } ;

Se puede constatar que el patrón del código corresponde a la tabla de secuencia de conmutación de Medio Paso, cada 1 en la tabla aparece un punto en rojo.


La corriente de cada bobina es relativamente alta y es necesario poner un “driver” para que el microcontrolador no entregue esta corriente si no la entrega cada transistor interno.

### Control del teclado

El teclado está minimizado para el uso de un solo pin, utilizando una entrada analógica de la siguiente manera.


El convertidor analógico/digital del microcontrolador “lee” el valor de voltaje del pin de entrada A7 y “entiende” qué botón se ha pulsado.

### ¿Cómo se programa?

Escornabot usa un módulo de Arduino, muy popular en el mundo DIY, donde se tiene que grabar el firmware de funcionamiento, que está totalmente disponible y documentado en https://github.com/escornabot

Se usa el entorno de desarrollo de Arduino y se puede hacer como taller de Informática el desarrollo completo o parcial del funcionamiento, evidentemente adecuando a la edad correspondiente.


### Entender el programa de funcionamiento

El programa de este Escornabot ha sido realizado por @caligari y seguidamente se va a describir la parte principal del funcionamiento.

Al abrir el firmware 1.4.3 o 1.6.2 Escornabot.ino con el entorno de Arduino, aparecen una serie de pestañas donde se muestran cada parte control.


La estructura del lenguaje de programación es parecida al C++, el programa se puede ejecutar en dos partes:
- void setup() es la configuración y se encuentra siempre al comienzo del programa, se configuran los pinMode, se inicializa la comunicación serie, etc y se ejecutará una sola vez después de cada encendido o después de un Reset con el pulsador de la placa.
- void loop() es la ejecución del código, como lectura de entradas y activación de salidas.

El archivo Configuration.h es dónde se aloja la parte más importante para entender el funcionamiento, la Configuración.

Cuando hay la línea empieza con dos // o más quiere decir que lo que viene a continuación es sólo comentarios que ha puesto el programador para entender su programa. El programa original está en color verde y los comentarios adicionales para detallar en color rojo.

Si no se tiene conocimientos de programación en C++ o C para Arduino, se puede ver una documentación muy bien detallada http://manueldelgadocrespo.blogspot.com/p/se-utiliza-para-la-comunicacion-entre_3.html

//////////////////////////////////////////////////////////////////////
///// general configuration
//////////////////////////////////////////////////////////////////////

// engine to use Define el motor a usar, este caso motor paso a paso
#define ENGINE_TYPE_STEPPERS

#define en C es un componente útil que permite al programador para dar un nombre a un valor constante antes de compilar el programa. Las constantes definidas en Arduino no ocupan ningún espacio de memoria de programa en el chip. El compilador reemplaza las referencias a estas constantes con el valor definido en tiempo de compilación. En Arduino define tiene la misma sintaxis que define en C:

No hay punto y coma después de la instrucción #define. Si se incluye uno, el compilador genera errores. Tampoco puede haber un signo (=) a un número valor (5) o (true), por ejemplo.

// button set to use (analog input, digital input) Configura el tipo de entrada que proviene de pulsadores Analógicos o Digitales
#define BUTTONS_ANALOG Define el tipo de entrada que proviene de pulsadores Analógicos //#define BUTTONS_DIGITAL Define el tipo de entrada que proviene de pulsadores Digitales (no está activado)

// milliseconds after a button is considered as pressed Define cuantos milisegundos, como mínimo, tiene que estar pulsado un botón, para evitar pulsos parásitos inesperados en esta línea de pulsadores.
#define BUTTON_MIN_PRESSED 30 // En este caso 30 ms

// milliseconds after a button is considered as long pressed Define cuantos milisegundos, cómo mínimo, tiene que estar un pulsador un botón, para considerar que se trata de una pulsación “larga”, para configurar giros de 60 grados.
#define BUTTON_LONG_PRESSED 1000 // En este caso 1000 ms que determina pulsación larga

// put to false to add movements to the program after its execution
#define PROGRAM_RESET_ALWAYS true // Hace un Reset de los movimientos al final de ejecutarse un ciclo programado.

// store configuration and program within internal EEPROM
#define USE_PERSISTENT_MEMORY false // Serviría para almacenar en la Eeprom los movimientos, pero no se utiliza esta funcionalidad

// memory capacity for program movements Define la cantidad de movimientos que se pueden almacenar en la memoria RAM
#define MOVE_LIMIT 100 // En este caso se podrán almacenar hasta 100 movimientos, se puede ampliar el número de movimientos programados, ocupando más memoria RAM, que se comparte con la que usa el propio programa, pero típicamente es suficiente. El microcontrolador ATMega328P de la placa Arduino dispone de 2K bytes de RAM y no sobra mucha, pero se podría, si es necesario, configurar para almacenar más movimientos, pero no se ha probado el límite).

// milliseconds for the "pause" movement Define cuantos milisegundos tendrá que estar pulsado el botón para programar una pausa
#define PAUSE_MOVE_MILLIS 1000 // En este caso 1000 ms, que determina una Pausa

// milliseconds delay before starting to move Define cuantos milisegundos esperará el robot para empezar a moverse
#define DELAY_BEFORE_GO 500 // En este caso se empezará a mover después de 500 ms

// milliseconds to pause after every movement Define cuantos milisegundos tendrá que estar pulsado el botón para programar una pausa
#define AFTER_MOVEMENT_PAUSE 0 // En este caso se empezará a mover después 0 ms después de una Pausa

// point of view set when Vacalourabot is started Escornabot (antes Vacalourabot)
#define POV_INITIAL POV_ESCORNABOT // Punto de vista (Point Of View) de la ejecución de los movimientos, es decir desde el usuario o desde el robot, pero no está implementado

// bluetooth serial Define el puerto serie que proviene del módulo Bluetooth
#define USE_BLUETOOTH true // Define el uso de modulo Bluetooth

#define BLUETOOTH_BAUDS 9600 // Define la velocidad de transmisión del módulo Bluetooth

// buzzer Define el Zumbador
#define USE_BUZZER true // Define el uso de modulo Bluetooth

#define BUZZER_PIN 10 // Define el pin usado por el Zumbador (en este caso D10)

#define PROGRAM_FINISHED_RTTL RTTL_FIDO // Buzzer,h // Define la musiquilla al final de la ejecución #define TONE_FREQ_UP 2637 // Define la frecuencia de 2637 (que corresponde a un Mi octava 7 musical) para señalizar que va hacia adelante

#define TONE_FREQ_RIGHT 4434 // Define la frecuencia de 4434 (que corresponde a un Do# octava 8 musical) para señalizar que gira a la derecha

#define TONE_FREQ_DOWN 3520 // Define la frecuencia de 3520 (que corresponde a un La octava 7 musical) para señalizar que va hacia atrás

#define TONE_FREQ_LEFT 2217 // Define la frecuencia de 2217 (que corresponde a un Do# octava 7) para señalizar que gira a la izquierda

Control del Zumbador

Una salida del microcontrolador PWM genera frecuencias que se pueden reproducir em un zumbador

En esta web se pueden encontrar cada nota musical con su correspondiente frecuencia y octava correspondiente
https://juegosrobotica.es/musica-con-arduino/#

Control del LED

// simple led Define el LED
#define USE_SIMPLE_LED false // Define el uso del LED #define SIMPLE_LED_PIN 13 // Define el pin 13 para uso del LED

// keypad leds Define los LED de los pulsadores
#define USE_KEYPAD_LEDS true

#define KEYPAD_LED_PIN_UP A0 // Define el pin A0 para el LED para señalizar que va hacia adelante #define KEYPAD_LED_PIN_RIGHT A3 // Define el pin A3 para uso del LED para señalizar que gira a la derecha

#define KEYPAD_LED_PIN_DOWN A2 // Define el pin A2 para uso del LED para señalizar que va hacia atrás #define KEYPAD_LED_PIN_LEFT A1 // Define el pin A1 para uso del LED para señalizar que gira a la izquierda

#define KEYPAD_LED_PIN_GO 13 // Define el pin 13 para el LED para señalizar que se pone en marcha

//////////////////////////////////////////////////////////////////////
///// Steppers engine setup // Configura los motores paso a paso //////////////////////////////////////////////////////////////////////

#ifdef ENGINE_TYPE_STEPPERS

#ifdef permite compilar una sección de un programa solo si la macro que se especifica como parámetro ha sido definida, sin importar cuál sea su valor.

// stepper pin setup (digital outputs) Configuración de los pines de control de los motores paso a paso #define STEPPERS_MOTOR_RIGHT_IN1 5
#define STEPPERS_MOTOR_RIGHT_IN2 4

#define STEPPERS_MOTOR_RIGHT_IN3 3

#define STEPPERS_MOTOR_RIGHT_IN4 2 #define STEPPERS_MOTOR_LEFT_IN1 9 #define STEPPERS_MOTOR_LEFT_IN2 8

#define STEPPERS_MOTOR_LEFT_IN3 7

#define STEPPERS_MOTOR_LEFT_IN4 6

// stepper pin setup (digital outputs) Configuración de los pines de control de los motores paso a paso con giro inverso
#define STEPPERS_MOTOR_RIGHT_IN1 2

#define STEPPERS_MOTOR_RIGHT_IN2 3

#define STEPPERS_MOTOR_RIGHT_IN3 4 #define STEPPERS_MOTOR_RIGHT_IN4 5 #define STEPPERS_MOTOR_LEFT_IN1 6 #define STEPPERS_MOTOR_LEFT_IN2 7

#define STEPPERS_MOTOR_LEFT_IN3 8

#define STEPPERS_MOTOR_LEFT_IN4 9

// step calibration Configuración de la calibración de los pasos
#define STEPPERS_STEPS_PER_SECOND 1000 // Define el número de pasos por segundo, se puede modificar hasta 2300 pasos, pero depende del motor y también de la alimentación de la batería

#define STEPPERS_LINE_STEPS 1738 // Define el número de pasos para cada paso (10 cm), se puede crear un tapete de juego con dimensiones diferentes, 1cm será de 174. A partir de aquí podemos cambiar el valor para que avance lo que queramos.

#define STEPPERS_TURN_STEPS 1024 // Define el número de pasos para cada giro (90 grados), para girar a 45 grados se puede modificar a 512 pasos, En caso de decimales redondear el valor.

Un juego; practicar las horas del reloj variando los ángulos de giro.

#endif

Estas directivas permiten incluir o descartar parte del código de un programa si se cumple una determinada condición.
#ifdef permite compilar una sección de un programa solo si la macro que se especifica como parámetro ha sido definida, sin importar cuál sea su valor.

Por ejemplo, digamos que tienes una aplicación y te gustaría que cuando estés desarrollando, siempre inicie con un usuario determinado.

En este caso las estas directivas te pueden ayudar:
#define PRUEBA

#ifdef PRUEBA

// CODIGO PARA CARGAR USUARIO POR DEFECTO

#endif

El código dentro de la directiva solo será compilado si PRUEBA está definida. Así cuando vayas a publica tu aplicación, solo tendieras que eliminar la definición de PRUEBA y el programa seguirá su flujo normal.

Control de los Pulsadores
Como se ha mostrado al principio los pulsadores están enlazados con resistencias a un solo pin, en el archivo Configuration.h

Por lo que esta parte de configuración Digital no está activada

////////////////////////////////////////////////////////////////////// ///// Button set digital
//////////////////////////////////////////////////////////////////////

#ifdef BUTTONS_DIGITAL

// keypad pin setup (digital or analog inputs) (use 255 if key doesn't exist) #define BS_DIGITAL_UP A0
#define BS_DIGITAL_RIGHT A1

#define BS_DIGITAL_DOWN A2

#define BS_DIGITAL_LEFT A3 #define BS_DIGITAL_GO A4

#define BS_DIGITAL_RESET 255

#endif // BUTTONS_DIGITAL

Esta parte si que es la que funciona

////////////////////////////////////////////////////////////////////// ///// Button set analog
//////////////////////////////////////////////////////////////////////

#ifdef BUTTONS_ANALOG

#define BS_ANALOG_WIRES 2 // WIRE 2 ?

//#define BS_ANALOG_WIRES 3 // no se usa

// keypad pin setup (analog input)
#define BS_ANALOG_PIN A7 // Configura el pin A7 como entrada de los Pulsadores

// input values for each key pressed (0 if key doesn't exist)
#define BS_ANALOG_VALUE_UP 512 // Valores para Pulsador Adelante

#define BS_ANALOG_VALUE_RIGHT 860 // Valores para Pulsador Derecha

#define BS_ANALOG_VALUE_DOWN 769 // Valores para Pulsador Atras #define BS_ANALOG_VALUE_LEFT 683 // Valores para Pulsador Izquierda #define BS_ANALOG_VALUE_GO 810 // Valores para Pulsador GO #define BS_ANALOG_VALUE_RESET 0 // Valores para RESET ?

#endif // BUTTONS_ANALOG

////////////////////////////////////////////////////////////////////// ///// Button set Bluetooth //Configuración del Bluetooth //////////////////////////////////////////////////////////////////////

#ifdef USE_BLUETOOTH

// Arduino serial port (default is Serial, use Serial1 with Arduino Micro)
//#define BLUETOOTH_SERIAL Serial si quitamos las barras // ya deja preparado para recibir datos a través del modulo Bluetooth
//#define BLUETOOTH_SERIAL Serial1
//#define BLUETOOTH_SERIAL Serial2
//#define BLUETOOTH_SERIAL Serial3

#endif // USE_BLUETOOTH

Modo de juego a 90 o 60 grados
El firmware está preparado para trabajar a 90 grados y a 60 grados con pulsación larga. La selección del tipo de juego viene definida en el archivo Enums.h

// game modes
enum
{
GAME_MODE_GRID_90 = 0, // squared grid (classical mode) GAME_MODE_GRID_60 = 1, // triangled grid
};
typedef uint8_t GAME_MODE;

Programación de los movimientos de “Saludo”
Los movimientos de “saludo” inicial al dar alimentación al Escornabot, están programados en la memoria Eeprom del microcontrolador, dónde quedan almacenadas, aunque se quite la alimentación y en el firmware está en el archivo MoveList.h

const static MOVE PROGRAM_ESCORNA_GREETING[] = {
MOVE_FORWARD, // Mueve hacia adelante
MOVE_LEFT, | // Mueve hacia la izquierda
MOVE_RIGHT, | // Mueve hacia la derecha
MOVE_RIGHT, | // Mueve hacia la derecha
MOVE_LEFT, | // Mueve hacia la izquierda
MOVE_BACKWARD, // Mueve hacia atrás
MOVE_NONE
};

Si se quieren programar otros movimientos, solo hay que modificar, quitar o añadir las líneas que se muestran en el archivo MoveList.h . El número de movimientos como se puede ver son 6, pero la memoria Eeprom permite una cantidad elevada de movimientos, tiene 1 KBytes

### Escornabot sigue creciendo

Además, Escornabot está preparado para añadir un módulo de Bluetooth tipo HM-10 con su App disponible para Android y IOs.


También está preparado para un módulo Wifi, aunque no es recomendable típicamente por el alto consumo con respecto al módulo Bluetooh, pero es posible.

El control remoto no es recomendable para los usuarios de menor edad, ya que es mejor trabajar encima de una mesa o en el suelo. En cambio, el uso de control remoto permite realizar otro tipo de prácticas como el diseño de un control desde un smartphone con AppInventor.

EngineSteppers.cpp

Es dónde hace girar en un sentido u otro los motores

void EngineSteppers::init()

{

pinMode(_config->motor_left_in1, OUTPUT);

pinMode(_config->motor_left_in2, OUTPUT);

pinMode(_config->motor_left_in3, OUTPUT);

pinMode(_config->motor_left_in4, OUTPUT);

pinMode(_config->motor_right_in1, OUTPUT);

pinMode(_config->motor_right_in2, OUTPUT);

pinMode(_config->motor_right_in3, OUTPUT);

pinMode(_config->motor_right_in4, OUTPUT);

// set coils in row // justo al alimentar hace este pequeño movimiento para estabilitzar la posición de las bobines de los motores

_movement_steps_r = 8;

_movement_steps_l = 8;

EVENTS->add(this);

}

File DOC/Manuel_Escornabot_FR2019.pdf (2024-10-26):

## Escornabot Singularis

Introduction
C'est un projet de robot éducatif ouvert, destiné à initier dans le domaine de
la robotique et de la programmation, des filles et des garçons, du plus petit au
plus grand ...


La construction peut être faite par presque n'importe qui. C'est ce qu'on appelle "faites-le vous-même", en anglais (DIY - Do It Yourself). Le corps du robot est réalisé avec une imprimante 3D et le contrôle avec Arduino.

Escornabot peut exécuter des séquences de mouvements programmés par l'utilisateur en appuyant sur les touches du robot. Vous pouvez également étendre votre contrôle en le pilotant depuis un téléphone portable ou une "tablette" via Bluetooth ou Wifi.

### Historique

En 2014, une équipe de galiciens formée par Tucho Méndez (professeur à l'origine de l'idée), Rafa Couto (chargé de la programmation), Xoán Sampaíño (concepteur des pièces en 3D) a commencé à travailler sur ce projet au sein de l'association Bricolabs. Plus tard Xabier Rosas a développé les circuits imprimés. Jorge Lobo et Miguel Gesterio se sont ajoutés ainsi que de nombreuses personnes qui collaborent à sa diffusion et développent ses prestations.

D'où vient le nom Escornabot ? C'est une composition d'escornaboi et de
robot (escorna + bot). Escornaboi est le mot en galicien de lucanus cervus
(Lucane cerf-volant, le plus grand coléoptère connu dans l'univers)

### Jouer avec l'Escornabot


Escornabot est un support didactique qui permet avec des commandes simples de réaliser des jeux au-dessus d’un gabarit, d’un tableau ou d’une carte. On peut commencer à jouer à partir de 3 ans, on peut "jouer" à l'apprentissage.


Jordi Mayné | v.2019


### Philosophie du Projet

C'est un projet matériel et logiciel libre, son évolution est donc ouverte à toute la communauté et tout le monde peut contribuer à son développement.

Vous pouvez trouver les détails du développement du projet, ainsi que des guides et manuels dans Github: https://github.com/pablorubma/escornabot-v2.12

La devise du projet est: Construire, Utiliser, Modifier et Partager.

### Types d'Escornabot

Il existe différents modèles, bien que leurs fonctionnements soient fondamentalement identiques, et nous nous concentrerons sur le modèle Singularis pour sa structure plus solide.


Placidus | DYI | Brivoi | Singularis

### Parties de l'Escornabot

La structure est construite avec une imprimante 3D, accessible à tous pour son prix avantageux. Le filament est biodégradable et peut être recyclé.

Les Fichiers STL sont disponibles sur :


https://github.com/pablorubma/escornabot-v2.12/tree/master/archivos-stl

Processeur Arduino

Moteurs pas à pas, LEDs, boutons, porte-piles…


Jordi Mayné | v.2019

### Comment fonctionne-t-il ?

L’Escornabot dispose d’un interrupteur général vous permettant de le mettre en marche et de 4 boutons vous permettant de programmer les mouvements que vous souhaitez effectuer, aller de l’avant (touche bleue), aller en arrière (touche noire), tournez à gauche (touche rouge), tournez à droite (touche verte) ; la touche blanche lui permettra d'exécuter la séquence de mouvements programmés. La touche blanche peut également arrêter la séquence lorsque l'Escornabot est en cours d'exécution.

Première étape : Salutations !!


Allumez l’interrupteur, une diode de la carte Arduino s’allume, attendez le premier bip et appuyez sur la touche blanche, puis l’Escornabot effectuera un mouvement d’accueil préprogrammé. Il ne fait cette séquence que lorsqu'il se met en marche.

À partir de là, vous pouvez programmer une série de mouvements. Chaque touche pressée le fera avancer d'un carreau sur le tableau soit 10 cm.

En fonction de l'âge de l'utilisateur, il est nécessaire de commencer à faire des mouvements pas à pas. Par exemple, avancer de 2 images, tourner à droite, avancer d’une image, tourner à gauche ...

Lorsque vous avez le contrôle des mouvements, vous pouvez programmer une séquence aussi longue et complexe que vous le souhaitez. Jusqu'à 100 mouvements peuvent être programmés.

### Habiller l'Escornabot

Vous pouvez «habiller» l'Escornabot pour changer son look «rustique», en utilisant du caoutchouc eva et certains détails décoratifs. Vous pouvez ajouter une pièce qui représentera le "visage" de l'Escornabot. Un

modèle est proposé comme base.

Jordi Mayné | v.2019

### Escornabot en profondeur

Parties de l'Escornabot
- 2 moteurs pour bouger les 2 roues
- 1 processeur pour séquencer les ordres donnés aux moteurs et LED de signalisation.
- 1 mémoire pour garder les ordres.
- 5 touches pour entrer les ordres
- 5 lampes d'indication.
- 1 buzzer pour entendre ce qu'il fait.
- 4 piles pour donner l'énergie à l'Escornabot
- 1 Interrupteur pour le mettre en marche.

Schéma de l'Escornabot

Moteur pas à pas


L'Escornabot intègre deux moteurs pas à pas, ce qui signifie qu'ils se déplacent par impulsions, ils intègrent également un réducteur ; un tour de roue est effectué toutes les 64 impulsions, ce qui permet une grande précision.

S'ils tournent dans le même sens, le robot avance ou recule. Si l'un tourne dans un sens et l'autre dans
le sens opposé, le robot pivote de 90 degrés à droite ou de 90 degrés à gauche.

Il existe une nouvelle version du micrologiciel qui peut pivoter à 45 et 90 degrés. Elle s’adresse aux utilisateurs plus âgés et elle permet un déplacement en diagonale.

Processeur Arduino
L'unité de contrôle de processus Arduino est le cerveau du robot. C'est là que sont stockées les instructions reçues du clavier et où sont contrôlés les moteurs, les voyants et le buzzer. Il intègre également un connecteur USB pour mettre à jour le micrologiciel du robot.


Jordi Mayné | v.2019

Comment changer les piles ?

Comme toute équipement, la durée de vie de la batterie n’est pas illimitée et il est nécessaire d’éteindre le robot chaque fois qu’il arrête de jouer car, même a l'arrêt, il continue de dépenser de l'énergie.

Si vous constatez que la séquence programmée ne se termine pas, les piles
sont probablement presque vides, même si le voyant d'alimentation est
allumé.


Pour changer les piles, éteignez d'abord le robot. En retournant le robot, vous trouverez une vis dans le support du porte-piles. Sous la boule, vous en trouverez une autre. Pour retirer la boule, effectuez une légère pression avec un petit tournevis.

Le support de piles est retiré et les 4 piles épuisées sont retirées et des nouvelles sont placées, le support de piles est replacé dans son emplacement et les vis et la boule sont remises en place.

Comment créer un tableau pour l'Escornabot

Sur une feuille ou un carton, il suffit de tracer des lignes tous les 10 cm en faisant une grille. L'Escornabot se déplace par pas de 10cm.


Dans l'adresse suivante, vous trouverez une collection de tableaux et une explication de l'activité à exécuter https://github.com/escornabot/docs/tree/master/Escornabot_Mats

Répertoire de Tableaux avec des instructions sur la façon de jouer : bit.ly/escornamats
Escornabot continue à grandir

De plus, Escornabot est prêt pour ajouter un module Bluetooth de type HM-10 avec son application disponible pour Android et IOS.

Il est également préparé pour un module Wifi, bien que cela ne soit généralement pas recommandé en raison de la consommation élevée par rapport au module Bluetooth, mais cela est possible.

Jordi Mayné | v.2019

### Programmation avec mBlock

Grâce à Angel Villanueva, une extension spécialement pour le robot Escornabot a été développée pour l'environnement de développement mBlock.

mBlock est un environnement de programmation graphique basé sur l'éditeur Scratch 2.0 créé par la société Makeblock qui vous permet de programmer non seulement les robots Makeblock eux-mêmes avec Scratch, mais également des robots basés sur Arduino tels que le robot Escornabot.

Vous trouverez plus d'informations sur le site web : http://www.mecatronicalab.es/programando-escornabot-con-mblock/


Cette application ouvre un espace dans le monde de la programmation, ce qui permet à l’Escornabot de pouvoir effectuer un parcours plus long.

### Contrôle gestuel

Tutoriel pour contrôler Escornabot par des gestes : http://www.mecatronicalab.es/escornabot-control-por-gestos/

### Commande vocale

Tutoriel pour contrôler Escornabot par la voix: http://www.mecatronicalab.es/escornavoz/

### EscornaScratch

Simulateur de mouvement Escornabot https://scratch.mit.edu/projects/339723274/


Jordi Mayné | v.2019

Qu'est-ce que la pensée informatique ?

La pensée informatique est une technique de résolution de problèmes utilisant des techniques et des concepts informatiques. Elle peut être utilisée pour résoudre des problèmes complexes de manière algorithmique et est parfois utilisée pour améliorer l'efficacité du processus. La pensée informatique est une compétence fondamentale non seulement pour les ingénieurs informaticiens, mais pour tout le monde, car elle s'applique à toutes les disciplines.
La pensée informatique ne concerne pas seulement les machines, mais aussi la manière de traiter les problèmes et les tâches à accomplir.

Avantages de la pensée Informatique

La pensée informatique ne s’applique pas seulement au monde informatique, bien au contraire. Les avantages pédagogiques de la capacité de penser à l’informatique sont divers, à commencer par l’utilisation d’abstractions qui améliorent et renforcent les capacités intellectuelles, et peuvent donc être transférés dans n’importe quel autre domaine.
La pensée informatique implique un ensemble de techniques et d'habiletés dans la résolution de problèmes que les programmeurs utilisent pour écrire les programmes qui constituent les applications informatiques qu'ils utilisent quotidiennement (moteurs de recherche, courriers électroniques, etc.). Robotique éducative

Il s’agit d’un système d’enseignement interdisciplinaire qui améliore le développement des aptitudes et des compétences des étudiants, leur permettant de tirer des enseignements de leur propre expérience au cours du processus de construction et de robotisation d’objets. L’interdisciplinarité est due au fait qu’elle inclut des concepts liés aux domaines de la science, de la technologie, de l’ingénierie et des mathématiques, ce qui en anglais est connu sous l’acronyme STEM (sciences, technologie, ingénierie, mathématiques), de la linguistique et de la créativité. En ce sens, les environnements de travail multidisciplinaires de la robotique éducative aident au développement de nouvelles compétences et de nouveaux concepts, renforçant ainsi la pensée systémique des étudiants.

Dans les environnements éducatifs, la robotique éducative peut être analysée sous deux angles: l'apprentissage de la robotique et l'apprentissage avec la robotique. Vous pouvez parler de robotique en éducation et de robotique pour l'éducation, en présentant deux approches dans lesquelles les étudiants doivent accéder à l’apprentissage de la robotique et à son utilisation pour apprendre des sujets dans divers domaines de connaissance.

Jordi Mayné | v.2019

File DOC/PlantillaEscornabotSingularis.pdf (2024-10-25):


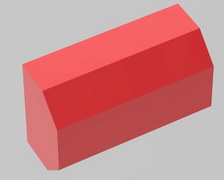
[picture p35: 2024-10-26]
Imatges/Afegit1.jpg

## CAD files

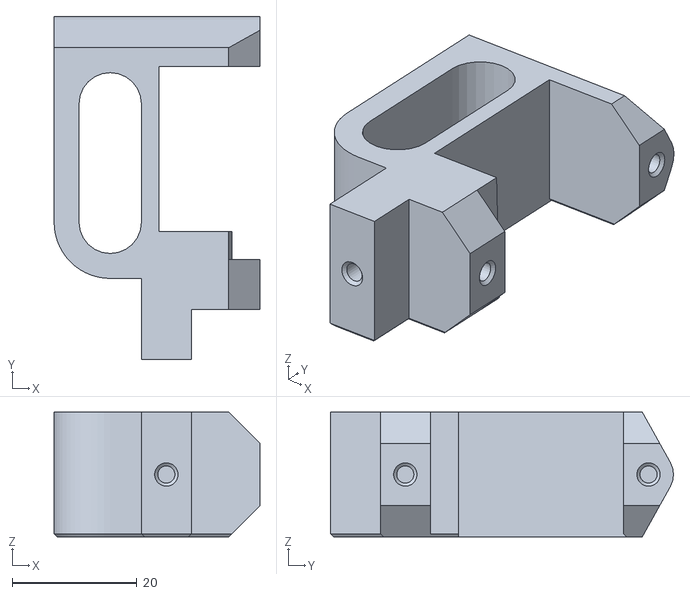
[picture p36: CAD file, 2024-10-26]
STL/BatteryBallcaster2.stl
33.0 x 55.0 x 20.0

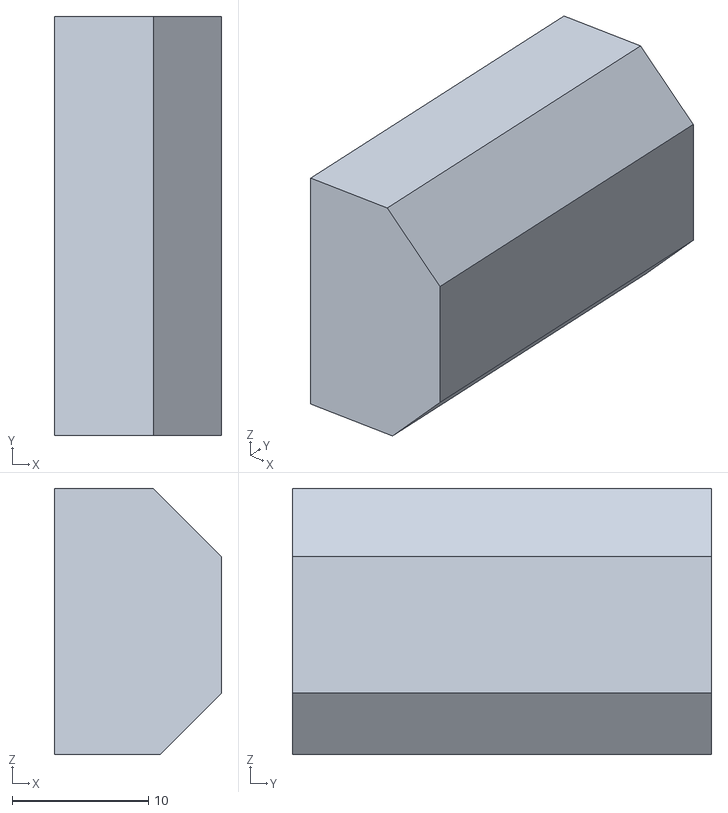
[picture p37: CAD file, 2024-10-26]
STL/TopeBateria9V.stl
12.3 x 30.8 x 19.5

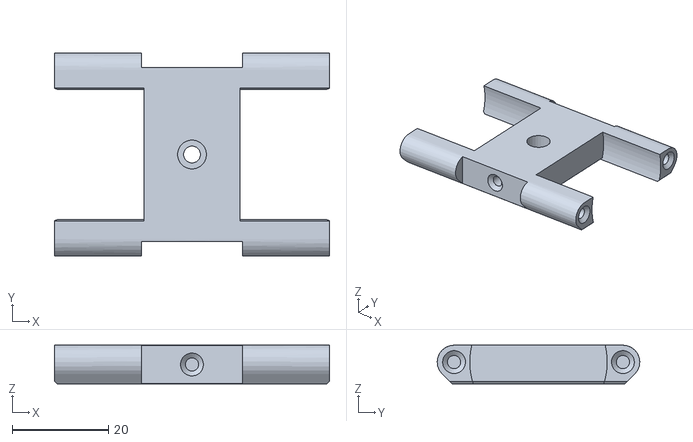
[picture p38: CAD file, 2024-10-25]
STL/MotorBracket.stl
57.0 x 42.0 x 8.00

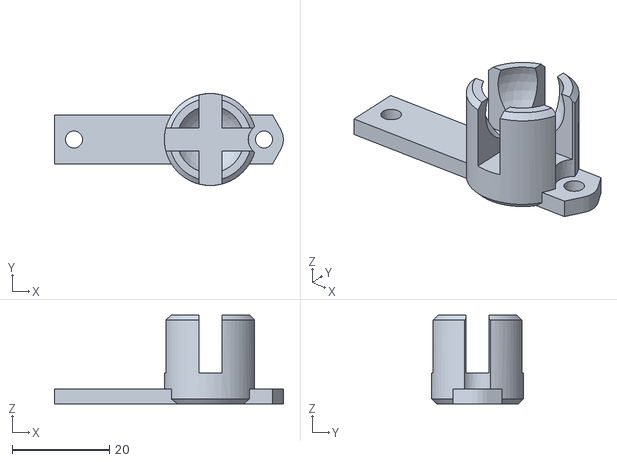
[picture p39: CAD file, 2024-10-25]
STL/ballcaster-v2.stl
47.0 x 18.9 x 18.2

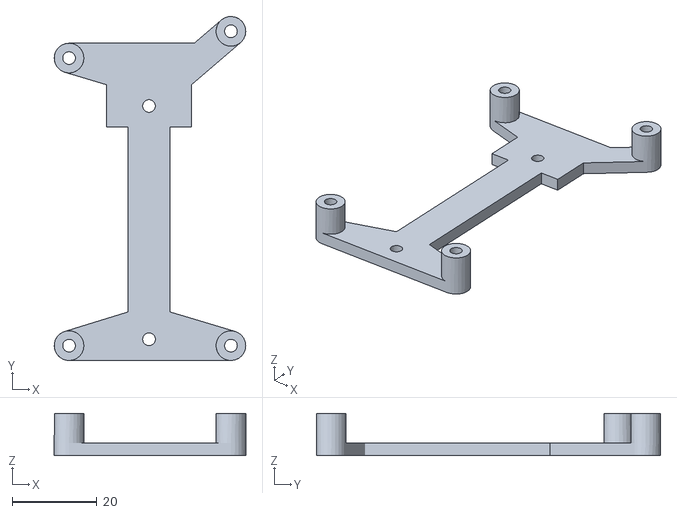
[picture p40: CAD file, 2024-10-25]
STL/cpu-2_10-bracket.stl
45.2 x 81.1 x 10.0

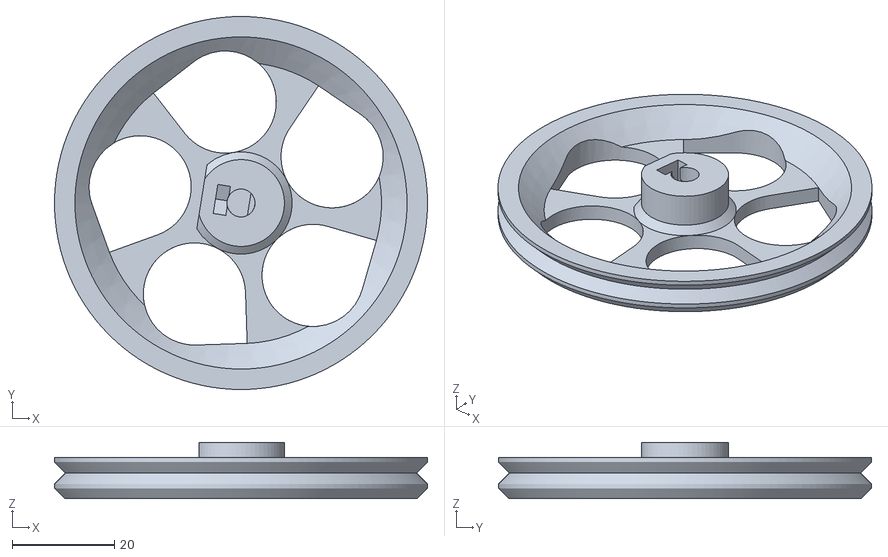
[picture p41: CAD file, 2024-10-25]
STL/wheel-l.stl
73.0 x 73.0 x 11.0

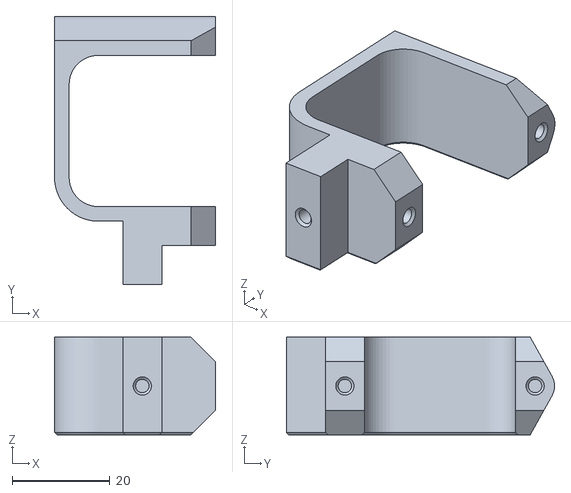
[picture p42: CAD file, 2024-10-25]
STL/battery-bracket.stl
33.0 x 55.0 x 20.0

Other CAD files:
STL/wheel-r.stl

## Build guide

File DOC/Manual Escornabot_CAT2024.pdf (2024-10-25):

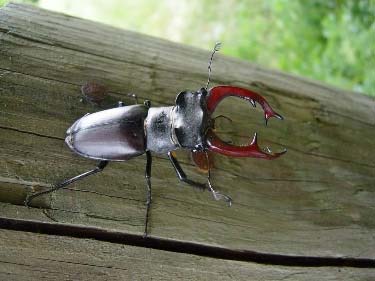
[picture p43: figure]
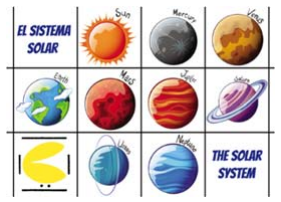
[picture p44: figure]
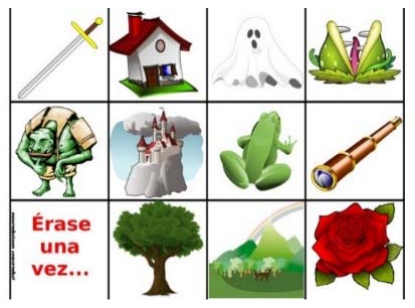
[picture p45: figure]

1 | Jordi Mayné | v.2024

## Escornabot Singularis

### Introducció

Es un projecte d’un robot educatiu obert, per iniciar a les nenes i els nens en
el camp de la robòtica i la programació, des de els més petits fins els més
grans...

La construcció del mateix el pot fer quasi qualsevol persona. Es el que es diu: “Fes-ho tu mateix”, en anglès (DIY - Do It Yourself). El cos del robot fet amb impressora 3D, i el control amb Arduino.

Escornabot pot executar seqüencies de moviments que son programats per l’usuari mitjançant la pulsació de les tecles del robot. També es pot ampliar el seu control per a poder ser manejat des d’un telèfon mòbil o una “tablet” a través de Bluetooth o Wifi.

### Historia

A 2014 un equip de gallecs format per, Tucho Méndez (professor que va tenir la idea), Rafa Couto (va fer la programació) i Xoán Sampaíño (va dissenyar les peces 3D), van començar a treballar en aquest projecte en l’associació Bricolabs. Desprès es van afegir Xabier Rosas que va dissenyar els
circuits impresos, Jorge Lobo i Miguel Gesterio i amb d’altres col·laboradors més
que ajuden a difondre i fer créixer aquest projecte per tot Espanya, per altres
països d’América Central, América del sud, França i Japó.

D’on ve el nom Escornabot? És una composició de escornaboi y robot (escorna+bot). Escornaboi es la paraula en gallec del lucanus cervus (cervol volant, el major escarabat conegut en l’univers)

### Jugar amb l’Escornabot

Escornabot és un mitjà didàctic que permet amb simples ordres dur a terme jocs sobre d’una plantilla, tauler o mapa. Es pot començar a jugar a partir dels 3 anys fins que un vulgui, es pot “jugar” aprenent.

### Filosofia del Projecte

Es un projecte de maquinari (Hardware) i programari (Software) lliure, pel que la seva evolució està oberta a la tota la comunitat i qualsevol pot contribuir a seu desenvolupament.

Es poden trobar els detalls del desenvolupament del projecte, així com guies i manuals en el seu Github de Pablo Rubio: https://github.com/pablorubma/escornabot-v2.12

La documentació està disponible en gallec, castellà, anglès i francès.

El lema del projecte és: Construeix, Usa, Modifica i Comparteix

### Tipus d’Escornabot

Existeixen diferents models encara que el seu funcionament es bàsicament el mateix, i ens centrem en el model Singularis per la seva estructura més sòlida.

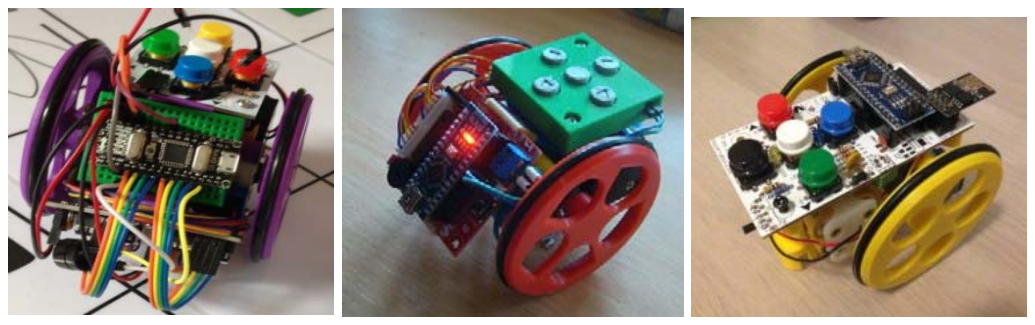
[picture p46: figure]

Placidus | DYI | Brivoi | Singularis

### Parts de l’Escornabot

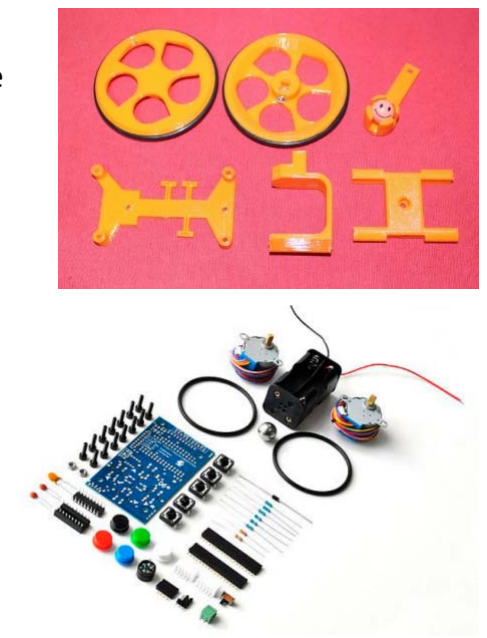
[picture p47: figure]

L’estructura està construïda amb una impressora 3D, que està a l’abast de tothom per el seu baix preu. El filament es biodegradable i es pot reciclar.

Arxius STL disponibles a: https://github.com/pablorubma/escornabot-v2.12/tree/master/archivos-stl

Processador Arduino

Motors pas a pas, LEDs, polsadors, porta-piles…

### Com es construeix?

Les peces de les estructura es fa amb una impressora 3D senzilla de 200x200 mm on caben les 6 peces que la componen. En moltes escoles que disposen d'una impressora 3D, s'ensenya a l'alumnat la impressió o la cura d'aquesta.

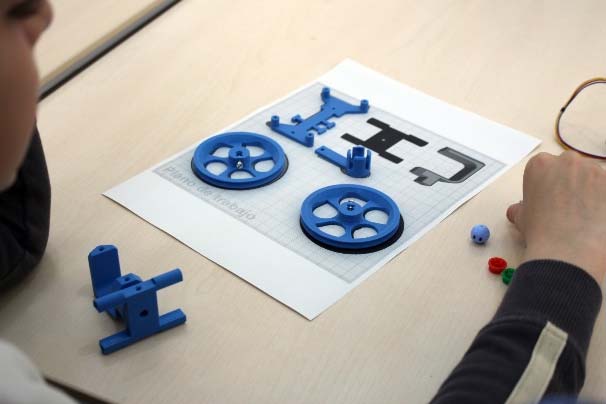
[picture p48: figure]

Fer la cara de l’Escornabot amb 3D permet realitzar un disseny d'aquesta "cara" personalitzada, fins i tot de l'interior de les rodes. Un taller que implica imaginació i l'ús d'eines 3D.

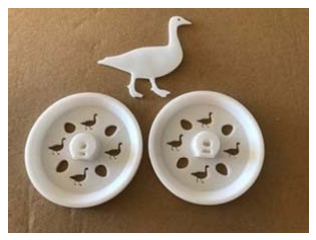
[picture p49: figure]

El muntatge és també molt simple ja que es subjecten les peces amb cargols. Està disponible una documentació completa per a fer un taller de muntatge, molt adequat per a realitzar a les escoles.

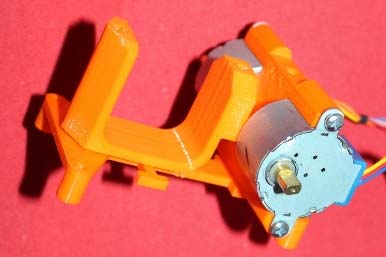
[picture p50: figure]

També hi ha disponible un taller complet de muntatge de la placa electrònica, evidentment primer cal fer un taller de soldadura del es disposa la informació i es pot fer a secundària amb les mesures de seguretat necessàries. Aquests tallers poden ser útils per al professorat o fins hi tot a famílies que volen aprendre o entrar al món de la robòtica DIY.

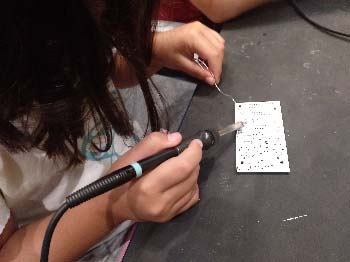
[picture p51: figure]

### Com funciona?

L’Escornabot disposa d’un interruptor general que permet posar en marxa, i 4 botons que permet programar els moviments que volem que faci, cada pulsació programada farà avançar 10 cm, permet moure endavant (botó blau), moure endarrere (botó negra), girar a l’esquerra (botó vermell), girar a la dreta (botó verd) i el botó del mig, de color blanc, farà que executi la seqüencia de moviments programats. També el botó blanc pot parar la seqüencia quan l’Escornabot està en marxa.

Primer pas: Salutació !!

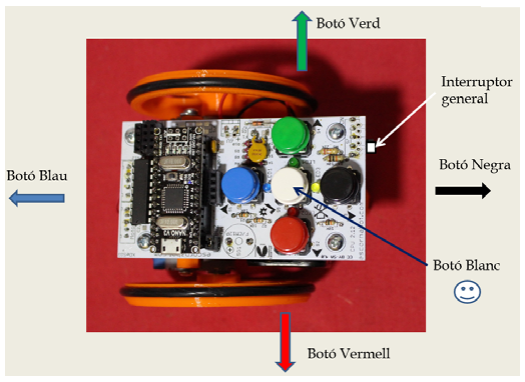
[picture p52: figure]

Posar el interruptor en marxa, un LED de la placa Arduino s’encén, esperar el primer “bip” i polsem el botó Blanc, llavors l’Escornabot realitzarà uns moviments pre-programats de salutació. Només fa aquesta seqüencia al posar en marxa.

A partir d’aquí ja es pot programar una sèrie de moviments, cada pulsació fa que avanci un quadre de tauler que equival a 10cm.

Segons l’edat del usuari, cal començar a fer moviments pas a pas. Per exemple, avançar 2 quadres, girar a la dreta, avançar 1 quadre, girar a l’esquerra...

Quan es te el control del moviments, es pot programar una seqüencia tan llarga i complexa com es vulgui. Es poden programar fins a 100 moviments.

### Vestir a l’Escornabot

Es pot “vestir” l’Escornabot per canviar el seu aspecte “rústic” del mateix, usant goma eva i alguns detalls decoratius. O afegir una peça que indiqui la “cara” del Escornabot. S’ofereix una plantilla com a base.

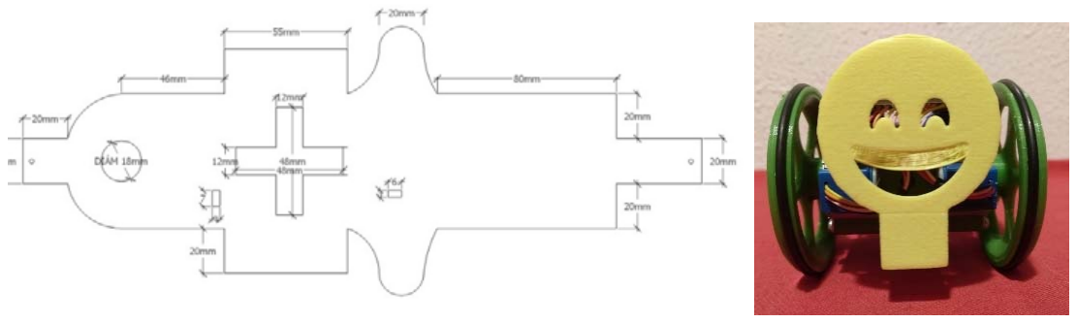
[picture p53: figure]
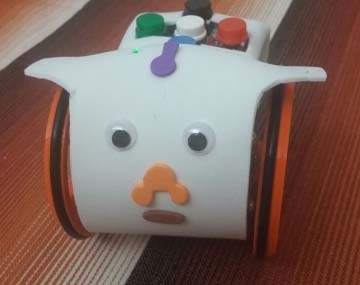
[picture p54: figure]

### Escornabot en profunditat

Parts de l’Escornabot

- 2 Motors per moure 2 rodes
- 1 Processador pera seqüenciar les ordres cap els motors i LEDs senyalització.
- 1 Memòria per guardar les ordres.
- 5 Botons per polsar les ordres.
- 5 Llums d’indicació.
- Brunzidor per sentir que està fent.
- 4 Piles per donar energia al Escornabot.
- Interruptor per posar en marxa.

Esquema del Escornabot

Motor pas a pas

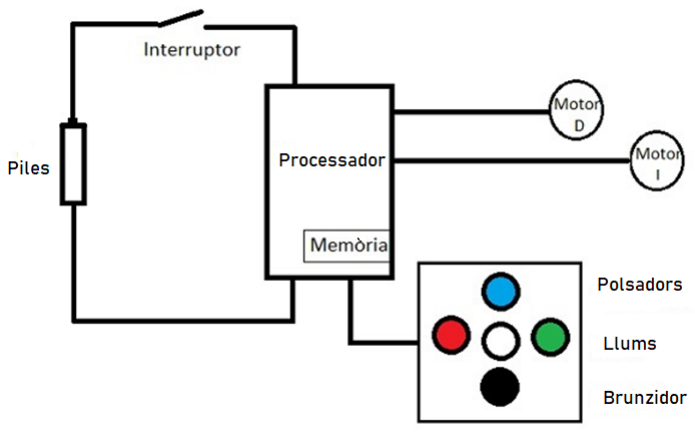
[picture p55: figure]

L’Escornabot incorpora dos motors pas a pas, vol dir que es mouen per impulsos i incorporen una reductora, cada 64 polsos dona una volta, el que permet una gran precisió.

Si giren en el mateix sentit el robot avança o retrocedeix, si un gira en un sentit i l’altre en
sentit contrari, el robot girarà 90 graus cap a la dreta o 90 graus cap a l’esquerra.

Hi ha una nova revisió de firmware que pot girar a 45 i a 90 graus, això es per usuaris més grans, i permet anar en diagonal.

Processador Arduino

La unitat de control de procés Arduino es el cervell del robot, es on es guarden les instruccions rebudes des de els botons i on es controlen els motors, LEDs i brunzidor. També incorpora un connector USB per poder actualitzar el firmware del robot.

### Com canviar les piles

Com qualsevol aparell la duració de les piles no es il·limitada, i cal apagar el robot cada cop que es deixi de jugar ja que encara que estigui parat segueix gastant.

Si veieu que no acaba la seqüencia programada, probablement que tingui les piles gairebé esgotades, encara que veiem el LED d’alimentació encès.

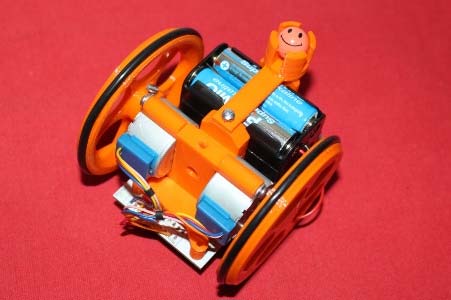
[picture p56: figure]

Per canviar les piles, primer apagueu el robot, donant la volta al robot
veureu un cargol en el suport del porta piles i sota la bola hi ha un altre, per
treure la bola amb un petit tornavís es treu la bola fent una petita pressió.

Es desplaça el porta-piles enfora i es treuen les 4 piles esgotades i es col·loquen les noves, es torna a posar el porta-piles en el suport i es posen de nou els cargols i la bola.

### Opció amb bateries

Si es vol fer servir bateries recarregables, cal modificar el suport del portapiles de l’actual Escornabot, per això fa falta imprimir la peça del porta-bateries.

o imprimir un suplement que es posarà en el suport del portapiles actual.

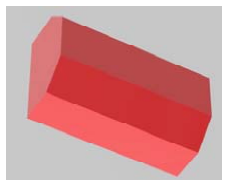
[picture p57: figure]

Aquestes bateries son del tipus 9V, es poden carregar a través d’un cable USB tipus C a 5V, el model mostrat es de 650mA/h i no dona més durada que les piles, però, la recarrega i un sol element pot millorar depenent de l’activitat que es faci.

Per un costat pot estar en carrega sense desmuntar la roda per canviar-la. En comprar aquest tipus de bateria s’ha de fixar en la posició que està el connector d’USB, ja que segons el fabricant col·loca en una posició o altra.

Finalment, es necessita comprar un cable clip per batería 9V

### Com fer un tauler per l’Escornabot

A partir d’un full o cartolina, es qüestió de traçar línies cada 10cm fent un quadriculat. L’Escornabot es mou en passos de 10cm dintre de la quadrícula. Aquí també la imaginació és infinita per dissenyar nous taulers per a "jugar" aprenent, es pot fer servir qualsevol material reciclat per posar obstacles en el recorregut, ajuntar diversos taulers amb un dibuix enorme (com el parxís que es va dissenyar amb 12 cartolines), o el tauler de Star Wars.

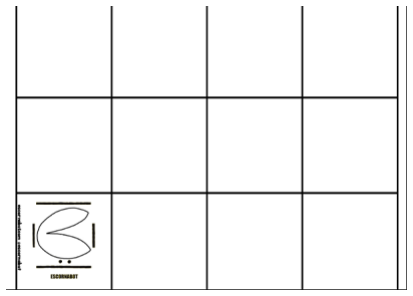
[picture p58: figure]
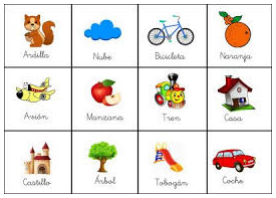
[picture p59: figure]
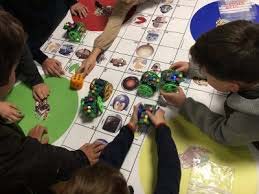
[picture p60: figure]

En la següent adreça es poden trobar una recopilació de taulers i una explicació de l’activitat a fer https://github.com/escornabot/docs/tree/master/Escornabot_Mats

Repositori de taulers amb indicacions de com jugar: bit.ly/escornamats

### ¿Cóm es programa?

Escornabot fa servir un mòdul de Arduino, molt popular en el mon DIY, on es te que gravar el firmware del funcionament que està totalment disponible i documentat a https://github.com/escornabot

Es fa servir l’entorn de desenvolupament de Arduino i es pot fer com taller d’Informàtica el desenvolupament complet o parcial del funcionament, evidentment adequant a la edat corresponent.

### Escornabot segueix creixent

A més, Escornabot està preparat per afegir un mòdul de Bluetooth tipus HM-10 amb la seva App disponible per Android i IOs.

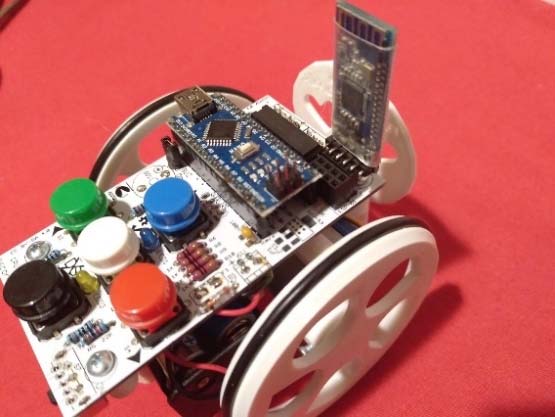
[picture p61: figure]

També està preparat per un mòdul Wifi, encara que no es recomanable típicament per el alt consumo amb respecte el mòdul Bluetooh, però es possible.

El control remot no és recomanable per els usuaris de menor edat, ja que és millor treballar sobre d'una taula o a terra. En canvi, l'ús de control remot permet realitzar un altre tipus de pràctiques com el disseny d'un control des d'un smartphone amb App Inventor.

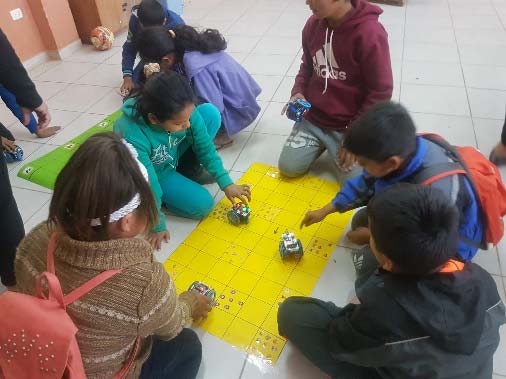
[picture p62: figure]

# Programació amb mBlock

Gràcies a Ángel Villanueva ha desenvolupat una Extensió específicament per el robot Escornabot per el entorn de mBlock.

mBlock es un entorn gràfic de programació basat en el editor Scratch 2.0 creat per l’empresa Makeblock que permet programar no sols els propis robots de Makeblock amb Scratch si no també robots basats en Arduino com es el cas del robot Escornabot.

Per més informació es pot trobar en la web: http://www.mecatronicalab.es/programando-escornabot-con-mblock/

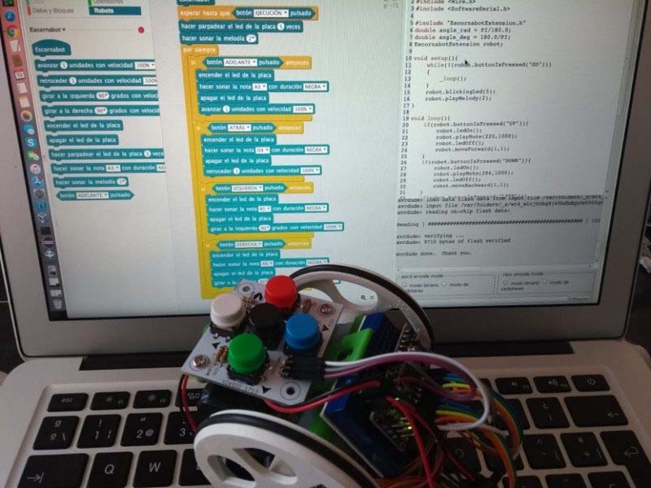
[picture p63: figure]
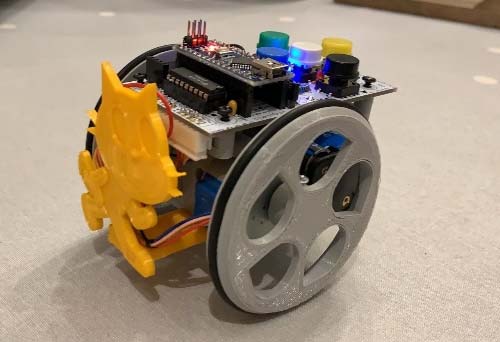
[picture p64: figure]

Aquesta aplicació obre un camp en el mon de la programació, que permet que l’Escornabot pugui tindre un recorregut molt llarg.

### Control d’Escornabot per gestos

Informació per controlar Escornabot per gestos: http://www.mecatronicalab.es/escornavoz/

### Control d’Escornabot per veu

Informació per controlar Escornabot per veu: http://www.mecatronicalab.es/escornavoz/

### EscornaScratch

Simulador de moviments de Escornabot https://scratch.mit.edu/projects/339723274/

### Visualino per Escornabot

També s’han creat blocs per poder treballar amb Visualino, una gran aportació. http://josema966.gitlab.io/bloques-en-visualino-para-escornabot.html

### Noves llibreries per Escornabot

La llibreria neix en el Club de Robòtica de Granada, per cobrir la necessitat de programar Escornabot en un entorn de programació textual (IDE Arduino). Escornabot en un principi ha estat dissenyat per programar-lo exclusivament amb la botonera pensant en el alumnat de primària, per tant per alumnat més gran i amb més capacitat d’abstracció (tercer cicle de primària i ESO) es feia necessari adaptar-li una sèrie d’instruccions per poder manegar l’Escornabot amb programació textual. La llibreria està desenvolupada per Prudencio Luna (@plunax) i Pedro Ruiz (@pedroruizf).

Està explicat en el manual https://github.com/escornabot/libreria-arduino/tree/master/manual

La llibreria es pot descarregar de https://github.com/clubroboticagranada/libreria-arduino-escornabot

### Escornabot a qualsevol lloc

Escornabot s’ha fet servir com a mitja de distracció fent tallers en exposicions dedicades a la robòtica com en la MakerFaire, Robotac… però també en hospitals d’oncologia infantil, inclús en centres geriàtrics i amb discapacitats.

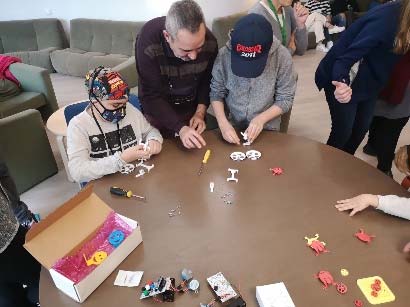
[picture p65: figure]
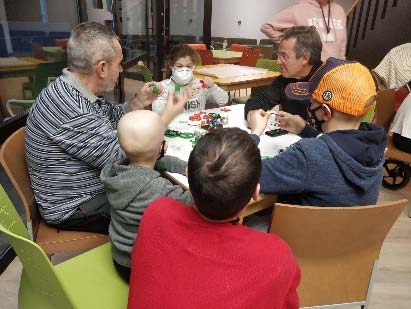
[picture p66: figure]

### Que és el pensament computacional?

El pensament computacional es una tècnica de resolució de problemes utilitzant tècniques i conceptes informàtics. Es pot emprar per a resoldre problemes complicats de manera algorítmica i sovint s’utilitza per a millorar l’eficiència de processos. El pensament computacional es una habilitat fonamental no solament per als enginyers informàtics si no per a tothom, ja que es aplicable a totes les disciplines.

El pensament computacional no només té a veure amb màquines, sinó amb la manera d’enfrontar-nos als problemes i a les tasques a realitzar.

### Beneficis del pensament computacional

El pensament computacional no és solament aplicable al món informàtic, al contrari. Els beneficis educatius de poder pensar de manera computacional són diversos, començant per l’ús d’abstraccions que milloren i reforcen les habilitats intel·lectuals, i que per tant poden ser transferits a qualsevol altre àmbit.

El pensament computacional implica un conjunt de tècniques i habilitats de resolució de problemes que els programadors utilitzen per escriure els programes que conformen les aplicacions informàtiques que utilitzem a diari (cercadors, email, etc).

### Robòtica educativa

Es tracta d'un sistema d'ensenyament interdisciplinari que potencia el desenvolupament d'habilitats i competències en l'alumnat, generant aprenentatge a partir de la pròpia experiència durant el procés de construcció i robotització d'objectes. La interdisciplinarietat es deu al fet que comprèn conceptes relacionats amb les àrees de Ciències, Tecnologia, Enginyeria i Matemàtiques el que en anglès es coneix amb les sigles STEM (Science, Technology, Engineering, Mathematics), així com àrees de Lingüística i també de Creativitat. En aquest sentit, els ambients multidisciplinaris de treball de la robòtica educativa ajuden al desenvolupament de noves habilitats i conceptes, enfortint el pensament sistèmic dels estudiants.

En entorns educatius, la robòtica educativa es pot analitzar des de dues perspectives: aprenentatge de la robòtica i aprenentatge amb robòtica. Es pot parlar de robòtica en educació i robòtica per a l'educació, presentant dos enfocaments en els quals l'alumnat ha d'accedir a l'aprenentatge de la robòtica i de la utilització d'aquesta en l'aprenentatge de temàtiques en diverses àrees del coneixement.

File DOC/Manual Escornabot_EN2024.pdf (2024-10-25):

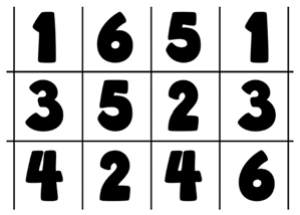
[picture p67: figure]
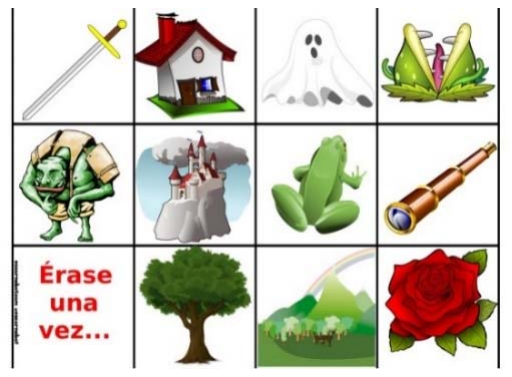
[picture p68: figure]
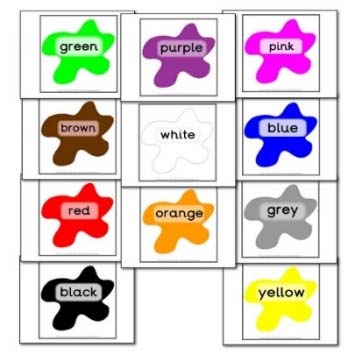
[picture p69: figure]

1 | Jordi Mayné | v.2024

## Escornabot Singularis

### Introduction

Escornabot is an open educational robot project, to initiate children in
robotics and programming fields, from the youngest (> 3 years) up to the
oldest ...

The construction of it can be done by almost anyone. DIY -Do It Yourself. The body of the robot is made with a 3D printer, and the control with Arduino.

Escornabot can execute sequences of movements that are programmed by the user, pressing the robot's buttons. It can also be extended to be managed from a mobile phone or a tablet via Bluetooth or Wifi.

### History

In 2014 a Galician team formed by Tucho Méndez (had the idea), Rafa Couto (programmer), Xoán Sampaíño (3D design) began working on this project in the Bricolabs association. Then Xabier Rosas (developed the printed circuit board), Jorge Lobo and Miguel Gesterio have also been added with more people who collaborate in their dissemination and grow their benefits.

Whence comes the Escornabot name? It is a happy composition of escornaboi
and robot (escorna+bot). Escornaboi is the word in Galician language for the
lucanus cervus (the biggest beetle in the well-known universe).

### Playing with Escornabot

Escornabot is a didactic means that allows with simple commands to carry out games on top of a template or map. From >3 years old until do you want, you can play and learning.

### Philosophy of the project

It is an Open Hardware (OSHW) and Free Software (FOSS) project, so its evolution is open to the community and anyone can contribute to its development.

You can find details of development of the project, as well as guides and manuals on Github.

https://github.com/pablorubma/escornabot-v2.12

The slogan of Project is: Build, Use, Modify and Share

### Types of Escornabot

There are different models, even its operation is practically the same, and we will focus on the Singularis model.


Placidus | DYI | Brivoi | Singularis

This documentation is dedicated exclusively to the Singularis version with the CPU v2.12

### Parts of Escornabot Singularis

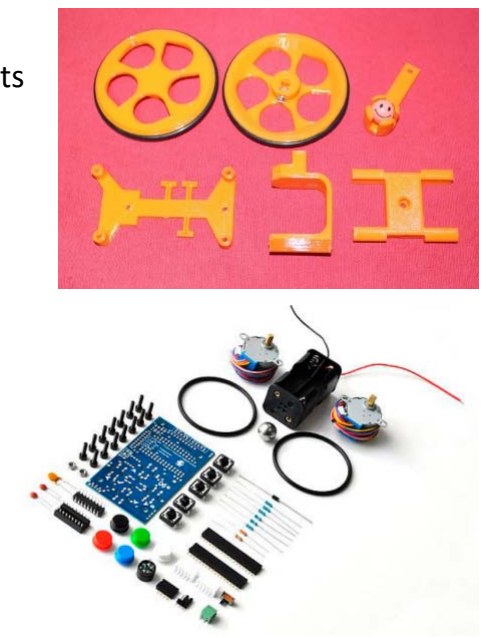
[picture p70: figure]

The structure is built with a 3D printer, which is available to everyone for its low price. The filament is biodegradable.

STL files available in: https://github.com/pablorubma/escornabot-v2.12/tree/master/archivos-stl

Arduino Nano Processor

Stepper Motors, LEDs, buttons, EscornaBoard, battery holder…

### How does it work?

Escornabot has a switch power, 4 buttons allow you to program the movements, you can move forward (blue button), move backward (black button), turn left (red button), turn to the right (green button) and the white button run the sequence of programmed movements. The white button can stop the sequence when the Escornabot is running.

Firts Step: ¡¡ Greeting !!

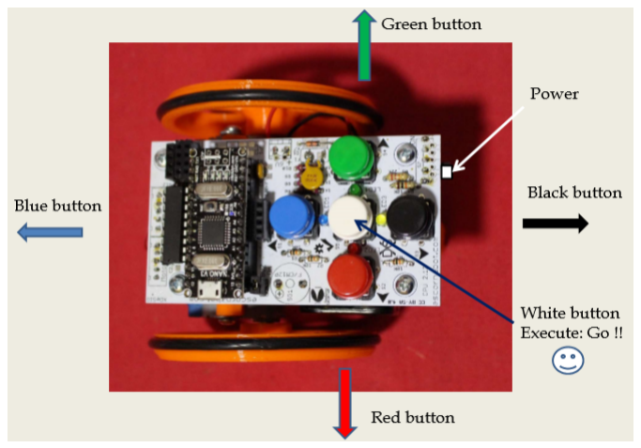
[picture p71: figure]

Switch-on the power and after first “beep”, push the White button, then the Escornabot will perform some greeting movements. It only does this sequence after switch-on.

From here, a series of movements can be programmed, each press will advance a panel of the board that is equivalent to 10cm.

Depending on the user age, it is necessary to start making movements step by step. For example, move forward 2 times, 1 turn right, 1 move forward 1 frame, 1 turn left ...

When you have control of the movements, you can program a sequence as long and complex as you want. Up to 100 movements can be programmed.

### Dress up the Escornabot

If your Escornabot is not pretty, you can "dress" it with your imagination, using eva rubber and some decorative details.

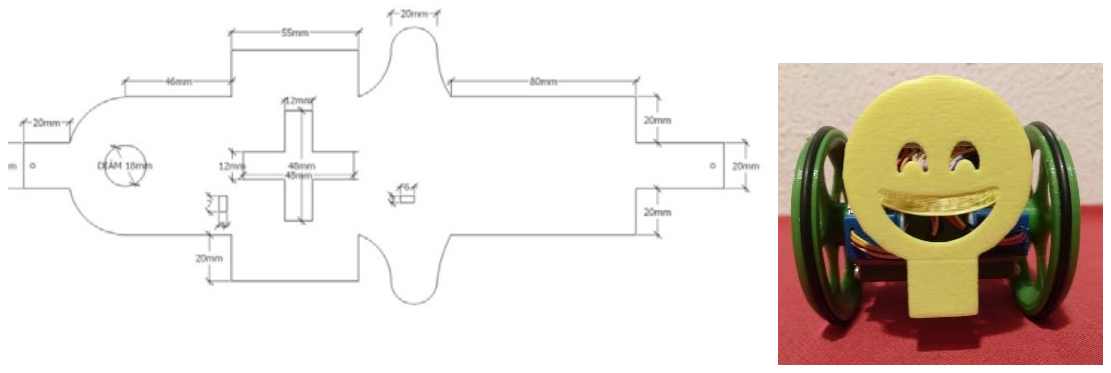
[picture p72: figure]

### Escornabot in deep

Parts of Escornabot

- 2 Stepper motors for to move every wheel
- 1 Arduino processor to sequence the orders to motors and lights.
- 1 Memory to save the orders.
- 5 Push buttons for to introduce the orders.
- 5 lights for indications.
- Buzzer, sound indication.
- 4 battery AA.
- Power switch.

Escornabot Scheme

Stepper Motor

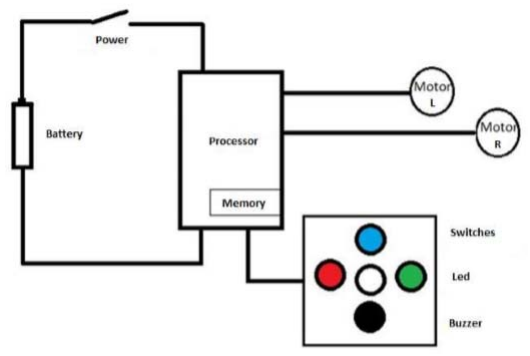
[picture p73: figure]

Escornabot have two stepper motors, which means that they move by impulses, they have a
reducer, every 64 pulses take a turn, which allows great precision.

If they rotate in the same direction the robot moves forward or backward, if one rotates in one direction and the other in the opposite direction, the robot will rotate 90 degrees to the right or 90 degrees to the left. There is a new firmware revision that can rotate at 45 and 90 degrees, this is for expert users, and allows to go in diagonal.

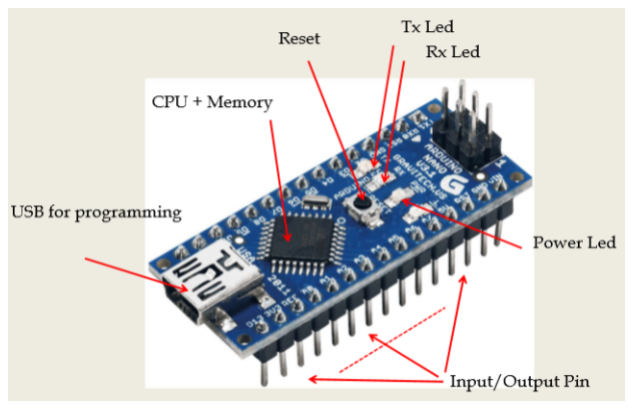
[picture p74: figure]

Arduino Processor

The Arduino process control unit is the brain of the robot, it is where are stored the instructions received from the keyboard and where the motors, LEDs and buzzer are controlled. Also have an USB connector for to update the firmware of the robot.

### How to change batteries?

The battery life is not unlimited, and it is necessary to turn off the robot every time finish to playing.

If you see that the programmed sequence does not end, probably have empty batteries, even if the power LED is on.


To change the batteries, first turn off the robot, flip the robot and will
find 2 screw for to fix the battery.

Then move out the battery holder and remove the batteries and place the new ones, put battery holder in the support, the screws.

### Option with batteries

If you want to use rechargeable batteries, you need to modify the support of the current Escornabot, so you need to print the part of the battery holder.

or to print the next part that will be placed in the current battery holder and then the battery.

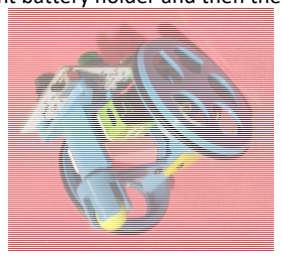
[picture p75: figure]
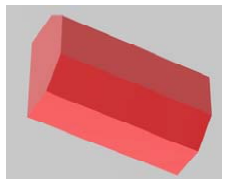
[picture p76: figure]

These batteries are of the 9V type, and can be charged from a USB Type C to 5V cable, the current of the model shown is 650mA/h and does not last longer than batteries, but recharging and a single cell can improve depending of the activity that is done.

On the one hand, it can be loaded without disassembling the wheel to change it. When buying this type of battery, you must pay attention to the position of the USB connector, as the manufacturer puts it in one position or another.

Finally, a 9V battery clip cable must be purchased

### How to do a board for the Escornabot

From a sheet or cardboard, you can draw lines every 10cm making a grid. The Escornabot moves in 10cm steps inside the grid. Then, the imagination is endless to design new boards to "play" learning, you can use any recycled material to put obstacles in the way, you can join several boards with a huge pattern (like the “parchis” that was designed with 12 cards) or a Star Wars board.

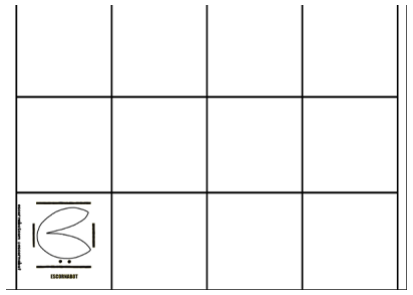
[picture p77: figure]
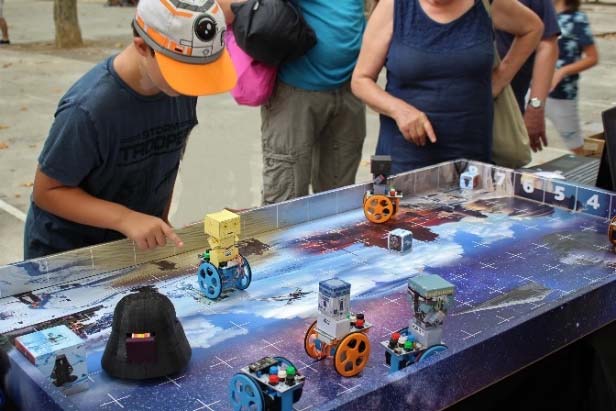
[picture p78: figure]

There are a collection of boards and some explanation of the activity to be performed: https://github.com/escornabot/docs/tree/master/Escornabot_Mats

Also, a board repository with some instructions: bit.ly/escornamats

### How is it programmed?

Escornabot uses an Arduino module, very popular in the DIY world, where the firmware must be programmed, it is fully available and documented at https://github.com/escornabot

The Arduino integrated development environment (IDE) can be used for developing the partial or full operation of Escornabot and can be done as a workshop, obviously adapting to the corresponding age.

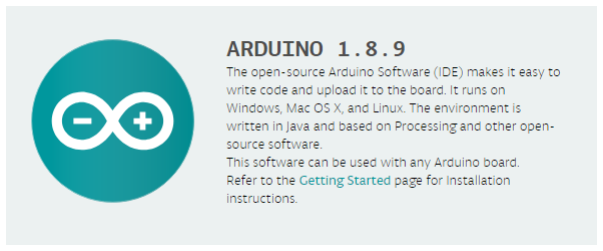
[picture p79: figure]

### Escornabot keeps growing

In addition, Escornabot is ready to add a Bluetooth module (like HM-10) with App available for Android and IOs.

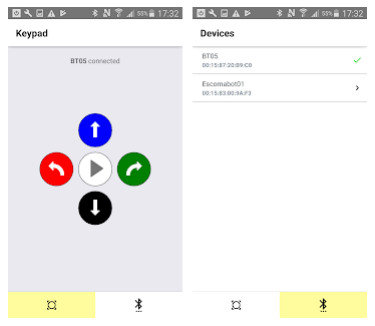
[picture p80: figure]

Also is ready for to use a Wifi module, but it is not recommended due the power consumption vs Bluetooh, but it is possible to use.

The remote control is not recommended for younger users, is better to work on the table or on the floor. Instead, the remote control allows other workshops like designing it for smartphone with AppInventor.

## Programming with mBlock

Thanks to Ángel Villanueva, he has developed an Extension specifically for the Escornabot robot from the mBlock development environment.

mBlock is a graphic programming environment based on the Scratch 2.0 editor created by Makeblock company that allows you to program not only the own Makeblock robots with Scratch, also Arduino-based robots such as the Escornabot.

For more information: http://www.mecatronicalab.es/programando-escornabot-con-mblock/


This application opens a field in the world of programming, which allows the Escornabot to have a very long way.

### Escornabot Gesture control

Information for to control the Escornabot by gesture: http://www.mecatronicalab.es/escornavoz/

### Escornabot Voice control

Information for to control the Escornabot by voice: http://www.mecatronicalab.es/escornavoz/

### EscornaScratch

Escornabot movements Simulator https://scratch.mit.edu/projects/339723274/

### Visualino for Escornabot

Blocks have also been created to work with Visualino, it is a great contribution. http://josema966.gitlab.io/bloques-en-visualino-para-escornabot.html

### New libraries for Escornabot

News libraries developed by Prudencio Luna (@plunax) and Pedro Ruiz (@pedroruizf) from Club de Robótica de Granada. https://github.com/escornabot/libreria-arduino/tree/master/manual

You can dowload from https://github.com/clubroboticagranada/libreria-arduino-escornabot

### Escornabot anywher

Escornabot has been used in workshops exhibitions like MakerFaire, Robotac ... but also in children's oncology hospitals, even in geriatric centers and with people with disabilities.


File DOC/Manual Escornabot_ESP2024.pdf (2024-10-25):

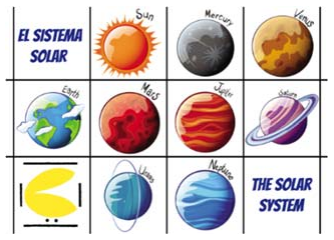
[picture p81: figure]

1 | Jordi Mayné | v.2024

## Escornabot Singularis

### Introducción

Es un proyecto de un robot educativo abierto, para iniciar a las niñas y niños en el campo de la robótica y la programación, desde los más pequeños hasta
los más grandes... a personas con alguna discapacidad, incluso a mayores de
edad y jubilados.

Escornabot no es un producto, es un robot para que lo pueda construir casi cualquier persona. Es lo que se llama: “Hazlo tú mismo”, en inglés (DIY - Do It Yourself). El cuerpo del robot está fabricado con una impresora 3D, y el control con Arduino.

Escornabot puede ejecutar secuencias de movimientos que son programados por el usuario mediante la pulsación de las teclas del robot. También se puede ampliar su control manejándose desde un teléfono móvil o una “tablet” a través de Bluetooth o Wifi.

### Historia

En 2014 un equipo de gallegos formado por Tucho Méndez (profesor que tuvo la idea), Rafa Couto (hizo la programación), Xoán Sampaíño (diseñó las piezas 3D) empezaron a trabajar en este proyecto en la asociación Bricolabs. Posteriormente se añadieron al proyecto Xabier Rosas que desarrolló los circuitos impresos, Jorge Lobo y Miguel Gesterio muchos mas colaboradores que ayudan a difundir y hacer crecer este proyecto por toda España, por países de América Central y América del sur, Francia y Japón.

¿De dónde viene el nombre Escornabot? Es una composición de escornaboi y robot (escorna+bot). Escornaboi es la palabra en gallego del lucanus cervus (ciervo volador, el mayor escarabajo conocido en el universo).

### Jugar con el Escornabot

Escornabot es un medio didáctico que permite con simples ordenes llevar a cabo juegos encima de una plantilla, tablero o mapa. Se puede empezar a jugar a partir de los 3 años hasta que uno quiera, se puede “jugar” aprendiendo.

### Filosofía del Proyecto

Es un proyecto de hardware y software libre, por lo que su evolución está abierta a toda la comunidad y cualquiera puede contribuir en su desarrollo.

Se pueden encontrar los detalles del desarrollo del proyecto, así como guías y manuales en su Github: https://github.com/pablorubma/escornabot-v2.12

La documentación está disponible en gallego, castellano, inglés y francés.

El lema del proyecto es: Construye, Usa, Modifica y Comparte

### Tipos de Escornabot

Existen diferentes modelos de estructura que han sido una evolución, con una electrónica que se ha montado en una placa de prototipado hasta en varios modelos de circuito impreso, que dependiendo del uso se adapta mejor a las necesidades educativas, pero su funcionamiento básicamente es el mismo, en este documento se centra en el modelo Singularis por su estructura de conexionado más sólida.

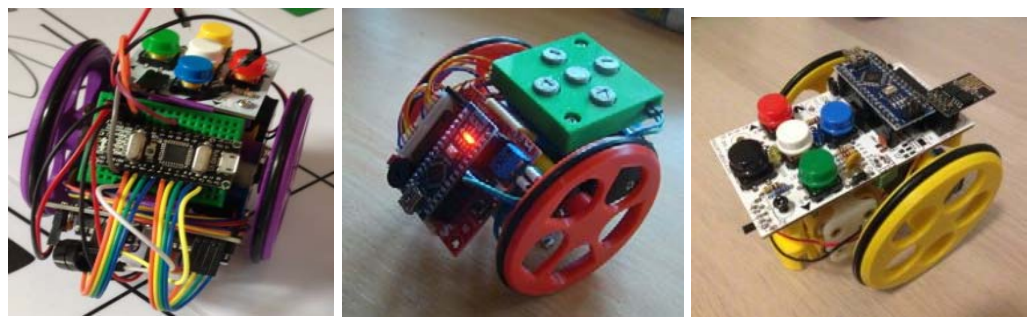
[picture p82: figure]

Placidus | DYI | Brivoi | Singularis

### Partes del Escornabot

La estructura está fabricada con una impresora 3D, que está al alcance de


todos por su bajo precio. El filamento es biodegradable y se puede reciclar.

Archivos STL disponibles en: https://github.com/pablorubma/escornabot-v2.12/tree/master/archivos-stl

Procesador Arduino

Motores paso a paso, LEDs, pulsadores, porta-pilas…

### ¿Cómo se construye?

Las piezas de las estructura se hace con una impresora 3D sencilla de 200x200 mm caben las 6 piezas que la componen. En muchas escuelas que disponen de una impresora 3D, se enseña al alumnado la impresión o el cuidado de esta.

Hacer la cara del Escornabot con 3D permite realizar un diseño de esta “cara” personalizada, incluso del interior de las ruedas. Un taller que implica imaginación y el uso de herramientas 3D.


El montaje es también muy simple ya que se sujetan las piezas con tornillos. Está disponible una documentación completa para hacer un taller de montaje, muy adecuado para realizar en las escuelas.


También hay disponible un taller completo de montaje de la placa electrónica, evidentemente primero es necesario hacer un taller de soldadura de la que se dispone la información y se puede hacer en secundaria con las medidas de seguridad necesarias. Estos talleres pueden ser útiles para el profesorado o hasta a familias que quieren aprender o entrar en el mundo de la robótica DIY.


### ¿Cómo funciona?

El Escornabot dispone de un interruptor general que permite poner en marcha, y 4 botones que permite programar los movimientos que queremos que haga, cada pulsación programada hará avanzar 10 cm, permite mover hacia adelante (tecla azul), mover hacia atrás (tecla negra), girar a la izquierda (tecla roja), girar a la derecha (tecla verde) y la tecla del medio de color blanco hará que ejecute la secuencia programada. También la tecla blanca puede parar la secuencia cuando el Escornabot está en marcha.

Primer paso: ¡¡Saludo !!


Al poner el interruptor en marcha, un LED de la placa Arduino se enciende, esperar al primer “bip” y pulsar la tecla Blanca, entonces el Escornabot realizará unos movimientos preprogramados de saludo. Solo hace esta secuencia al conectar alimentación.

A partir de aquí ya se puede programar una serie de movimientos, como se ha indicado cada pulsación hará que avance un cuadro del tablero que equivale a 10cm.

Para usarlo en edad muy temprana, hace falta empezar a hacer movimientos paso a paso. Por ejemplo, avanzar 2 cuadros, después programar girar a la derecha, seguidamente programar avanzar 1 cuadro, … girar a la izquierda...

Cuando ya se tiene el control de los movimientos, se puede programar una secuencia tan larga y compleja como se quiera. Se pueden programar hasta 100 movimientos.

### Vestir al Escornabot

Se puede “vestir” al Escornabot para cambiar su aspecto “rústico” del mismo, usando goma eva y algunos detalles decorativos. O añadir una pieza que indique la “cara” del Escornabot. Se ofrece una plantilla como base. Y existen algunos modelos de la cara, pero esto permite hacer un taller de diseño.


### Escornabot en profundidad

Partes del Escornabot

- 2 motores para mover 2 ruedas
- 1 procesador para la secuencia las ordenes hacia los motores y LEDs de señalización.
- 1 memoria para guardar las órdenes.
- 5 teclas para pulsar las órdenes.
- 5 luces de indicación.
- Zumbador para sentir que está haciendo.
- 4 pilas para dar energía al Escornabot.
- Interruptor para poner en marcha.

Esquema del Escornabot

Motor paso a paso


El Escornabot incorpora dos motores paso a paso, quiere decir que se mueven por impulsos, también incorporan una reductora, cada 64 pulsos dan una vuelta, que permite una gran precisión.

Si giran en el mismo sentido el robot avanza o retrocede, si uno gira en un sentido y el otro
en sentido contrario, el robot girará 90 grados hacia la derecha o 90 grados hacia la izquierda.

Hay una nueva revisión de firmware que puede girar a 45 y a 90 grados, esto es para usuarios más grandes, y permite ir en diagonal.

Procesador Arduino

La unidad de control de proceso Arduino es el cerebro del robot, es donde se guardan las instrucciones recibidas desde el teclado y donde se controlan los motores, LEDs y zumbador. También incorpora un conector USB para poder actualizar el firmware del robot.

### ¿Cómo cambiar las pilas?

Como cualquier equipo, la duración de las pilas no es ilimitada, y hace falta apagar el robot cada vez que se deje de jugar ya que aún que esté parado sigue gastando.

Si se ve que no acaba la secuencia programada, probablemente que tenga las pilas casi agotadas, aún que se vea el LED de alimentación encendido.

Par cambiar las pilas, primero apagar el robot, dando la vuelta al robot se
encontrará un tornillo en el soporte del porta pilas y debajo de la bola hay
otro, para sacar la bola con un pequeño destornillador se saca la bola haciendo una pequeña presión.

Se desplaza el porta-pilas hacia fuera y se sacan las 4 pilas agotadas y se colocan las nuevas, se vuelve a poner el porta-pilas en el soporte y se ponen de nuevo los tornillos y la bola.

### Opción con baterías

Si se quieren usar baterías recargables, hace falta modificar el soporte del actual Escornabot, para esto hace falta imprimir la pieza del porta-baterías.

o imprimir un suplemento que se pondrá en la pieza portapilas actual.

Estas baterías son del tipo 9V, se pueden cargar a través de un cable USB tipo C a 5V, el modelo mostrado es de 650mA/h y no da más duración que les pilas, pero la recarga y un solo elemento puede mejorar dependiendo de la actividad que se haga.

Por un lado, puede estar en carga sin desmontar la rueda para cambiarla. Al comprar este tipo de batería se ha de fijar en la posición que está el conector de USB, ja que según el fabricante coloca en una posición u otra.

Finalmente, se tiene que comprar un cable clip para batería 9V

### ¿Como hacer un tablero para Escornabot?

A partir de una hoja o cartulina, es cuestión de trazar líneas cada 10cm haciendo un cuadriculado. El Escornabot se mueve en pasos de 10cm dentro del cuadriculado. Aquí también la imaginación es infinita para diseñar nuevos tableros para “jugar” aprendiendo, se pueden usar cualquier material reciclado para poner obstáculos en el recorrido, juntar varios tableros con un dibujo enorme (como el parchís que se diseñó con 12 cartulinas), o el tablero de Starwar.


En la siguiente dirección se pueden encontrar una recopilación de tableros y una explicación de la actividad a realizar https://github.com/escornabot/docs/tree/master/Escornabot_Mats
Repositorio de tableros con indicaciones de como jugar: bit.ly/escornamats

### ¿Cómo se programa?

Escornabot usa un módulo de Arduino, muy popular en el mundo DIY, donde se tiene que grabar el firmware de funcionamiento, que está totalmente disponible y documentado en https://github.com/escornabot

Se usa el entorno de desarrollo de Arduino y se puede hacer como taller de Informática el desarrollo completo o parcial del funcionamiento, evidentemente adecuando a la edad correspondiente.

### Escornabot sigue creciendo

Además, Escornabot está preparado para añadir un módulo de Bluetooth tipo HM-10 con su App disponible para Android y IOs.


También está preparado para un módulo Wifi, aunque no es recomendable típicamente por el alto consumo con respecto al módulo Bluetooh, pero es posible.

El control remoto no es recomendable para los usuarios de menor edad, ya que es mejor trabajar encima de una mesa o en el suelo. En cambio, el uso de control remoto permite realizar otro tipo de prácticas como el diseño de un control desde un smartphone con AppInventor.

# Programación con mBlock

Gracias a Ángel Villanueva ha desarrollado una Extensión específicamente para el robot Escornabot para el entorno de desarrollo de mBlock.

mBlock es un entorno gráfico de programación basado en el editor Scratch 2.0 creado por la empresa Makeblock que permite programar no solo los propios robots de Makeblock con Scratch si no també robots basados en Arduino como es el caso del robot Escornabot.

Para más información se puede encontrar en la web: http://www.mecatronicalab.es/programando-escornabot-con-mblock/


Esta aplicación abre un campo en el mundo de la programación, permitiendo que Escornabot tenga un recorrido muy largo.

### Control de Escornabot por gestos

Información para controlar Escornabot por gestos: http://www.mecatronicalab.es/escornavoz/

### Control de Escornabot por voz

Información para controlar Escornabot por voz: http://www.mecatronicalab.es/escornavoz/

### EscornaScratch

Simulador de movimientos del Escornabot https://scratch.mit.edu/projects/339723274/

### Escornabot con Arduinoblocs

Con el entorno de desarrollo de Arduinoblocks www.arduinoblocks.com se ha desarrollado un control programado con bloques, ahora mismo está en una versión beta, y cualquiera puede ayudar al desarrollo completo.

http://www.arduinoblocks.com/web/project/editor/1383471


Escornabot es de software abierto y de hardware abierto.

### Escornarover y EscornaStemfie

Son dos proyectos realizados por Opcion3D https://opcion3d.com/: Escornarover es una estructura diferente con algunas diferencias de movimiento al tener cuatro ruedas tiene algunas particularidades que facilita la programación. EscornaStemfie es una estructura diferente de Escornabot bajo las características del juego de montaje impreso en 3D de Stemfie www.stemfie.com


https://www.thingiverse.com/thing:4911480


https://www.printables.com/model/286405-escornabot-stemfie-robot-fusion

### Visualino para Escornabot

También se han creado bloques para poder trabajar con Visualino, una gran aportación. http://josema966.gitlab.io/bloques-en-visualino-para-escornabot.html

### Nuevas librerías para Escornabot

La librería nace en el Club de Robótica de Granada, para cubrir la necesidad de programar Escornabot en un entorno de programación textual (IDE Arduino). Escornabot en un principio ha estado diseñado para programarlo exclusivamente con la botonera pensando en el alumnado de primaria, por tanto, para el alumnado mayor y con más capacidad de abstracción (tercer ciclo de primaria y ESO) se hacía necesario adaptarle una serie de instrucciones para poder manejar el Escornabot con programación textual. La librería está desarrollada por Prudencio Luna (@plunax) y Pedro Ruiz (@pedroruizf).

Está explicado en el manual https://github.com/escornabot/libreria-arduino/tree/master/manual

La librería se puede descargar desde https://github.com/clubroboticagranada/libreria-arduino-escornabot

### Escornabot en cualquier lugar

Escornabot se ha utilizado como medio de distracción, haciendo talleres en exposiciones dedicadas a la robótica como la MakerFaire, Robotac… pero también en hospitales de oncología infantil, incluso en centros geriátricos y con personas con discapacidades.


### ¿Qué es el pensamiento computacional?

El pensamiento computacional es una técnica de resolución de problemas utilizando técnicas y conceptos informáticos. Se puede emprar para resolver problemas complicados de manera algorítmica y a veces se utiliza para mejorar la eficiencia de procesos. El pensamiento computacional es una habilidad fundamental no solamente para los ingenieros informáticos si no para todos, ya que es aplicable a todas las disciplines.

El pensamiento computacional no solo tiene que ver con las máquinas, sino con la manera de enfrentarse a los problemas y a les tareas a realizar.

### Beneficios del pensamiento computacional

El pensamiento computacional no es solamente aplicable al mundo informático, al contrario. Los beneficios educativos de poder pensar de manera computacional son diversos, empezando por el uso de abstracciones que mejoran y refuerzan las habilidades intelectuales, y que por tanto puede ser transferidos a cualquier otro ámbito.

El pensamiento computacional implica un conjunto de técnicas y habilidades de resolución de problemas que los programadores utilizan para escribir los programas que conforman las aplicaciones informáticas que utilizan a diario (buscadores, email, etc).

### Robótica educativa

Se trata de un sistema de enseñanza interdisciplinaria que potencia el desarrollo de habilidades y competencias en el alumnado, generando aprendizaje a partir de la propia experiencia durante el proceso de construcción y robotización de objetos. La interdisciplinariedad se debe al hecho que comprende conceptos relacionados con las áreas de Ciencias, Tecnología, Ingeniería y Matemáticas el que en inglés se conoce con las siglas STEM (Science, Technology, Engineering, Mathematics), así como áreas de Lingüística y también de Creatividad. Añadiendo también la A de artístico. En este sentido, los ambientes multidisciplinarios de trabajo de la robótica educativa ayudan al desarrollo de nuevas habilidades y conceptos, fortaleciendo el pensamiento sistémico de los estudiantes.

En entornos educativos, la robótica educativa se puede analizar desde dos perspectivas: aprendizaje de la robótica y aprendizaje con la robótica. Se puede hablar de robótica en educación y robótica para la educación, presentando dos enfoques en los cuales el alumnado ha de acceder al aprendizaje de la robótica y de la utilización de esta en el aprendizaje de temáticas en diversas áreas del conocimiento.
